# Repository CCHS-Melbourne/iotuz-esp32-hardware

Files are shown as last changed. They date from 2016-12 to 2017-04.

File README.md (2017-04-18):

IoTuz - The Internet of Tuz
=============

Welcome to the linux.conf.au 2017 Open Hardware Project.  You can see information about this and other MiniConfs at http://www.openhardwareconf.org/wiki/Main_Page

This year we're bringing a project with the hottest new micro for people to have a play with. The ESP32 is the successor to the hugely popular ESP8266 chip we used for 2016 Open Hardware Project, the (ESPlant, https://github.com/CCHS-Melbourne/ESPlant).

The ESP32 is definitely the big brother of the ESP8266.  Included in it's features: 2.4 GHz Wi-Fi, Bluetooth, Dual Core CPUs

As usual we've got a custom board and some custom software to get you started on your journey!  Check out the subdirectories in this repo for more information.

IoTuz firmware can be found at https://github.com/CCHS-Melbourne/iotuz-esp32-firmware

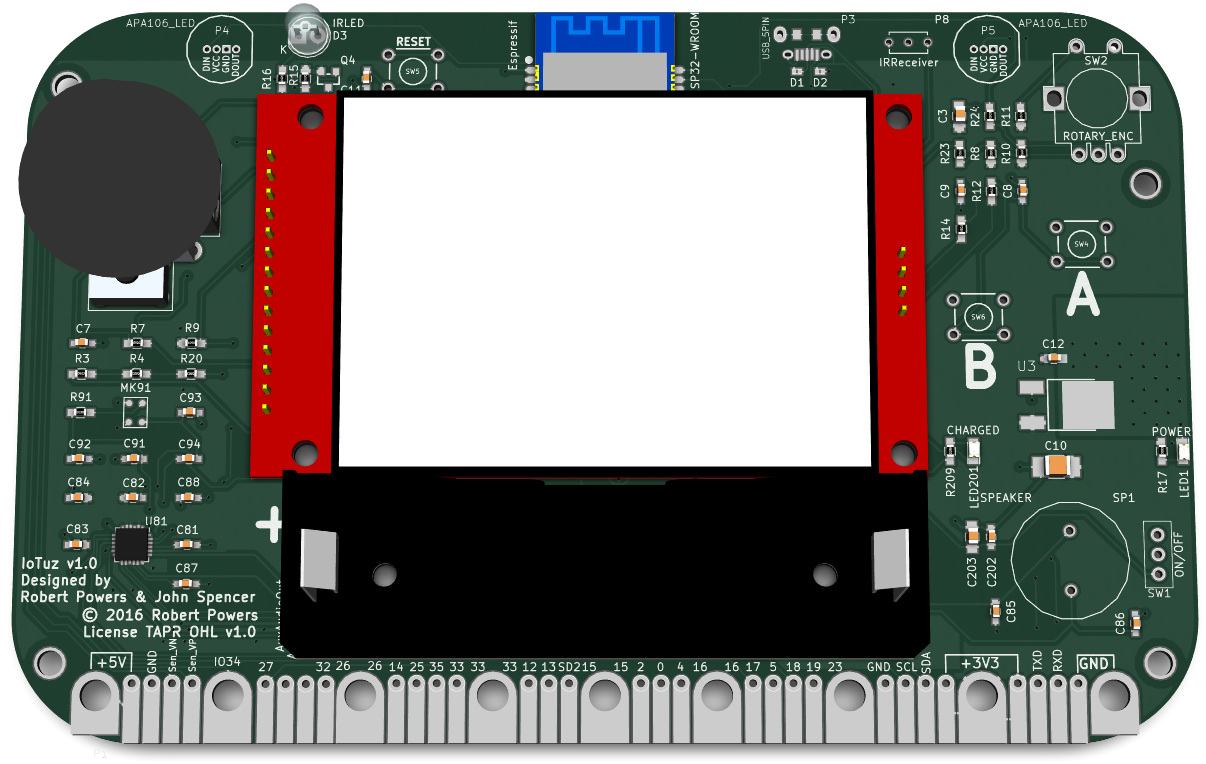
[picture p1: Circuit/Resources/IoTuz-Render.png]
IoTuz Render


Hardware assembly instructions
------------------------------
[Workshop assembly instructions](https://github.com/CCHS-Melbourne/IoTuz/wiki/Assembly-Instructions)
for people attending the LCA2017 Open Hardware Mini-Conference.

Software instructions
---------------------

[Software setup instructions](https://github.com/CCHS-Melbourne/IoTuz/wiki/Software-Instructions)

Please see https://github.com/marcmerlin/IoTuz mentioned below for an arduino driver.

Features
--------

[Marc MERLIN has written a driver for the arduino environment](https://github.com/marcmerlin/IoTuz) with support for:
- TFT (hw SPI)
- Touchscreen (hw SPI)
- Replacement touchscreen support (calibration option in case your touchscreen is reversed or has different calibration)
- Rotary Encoder via pin interrupt driven driver
- Support for A and B buttons "hidden" behind the I2C IO multiplexer
- Joystick
- Color LEDs
- Accelerometer
- BME280 (temperature, humidity, pressure)
- IO expander (pcf8574)
- Infrared receiver





For this software, go to: https://github.com/marcmerlin/IoTuz

Getting IoTuz
---------------
You need to clone the IoTuz repo from github, using the `--recursive` option to pick up submodules. If you download a zip file then the submodule parts will be missing, so we recommend using git to get it.

The command is:
```
git clone --recursive https://github.com/CCHS-Melbourne/IoTuz
```

Where to Now?
-------------

Check out (and contribute to) [the wiki](https://github.com/CCHS-Melbourne/IoTuz/wiki). There is a pinout summary, sensor summary, power information, etc.

CREDITS
------------

Made at hackmelbourne.org !

This project was designed by the 2017 linux.conf.au Open Hardware Team!
 - [Bob Powers](https://github.com/rdpowers)
 - [John Spencer](https://github.com/mage0r)
 - [Angus Gratton](https://github.com/projectgus)
 - [Andy Gelme](https://github.com/geekscape)
 - [Jon Oxer](https://github.com/jonoxer)
 - [Mark Wolfe](https://github.com/wolfeidau)
 - [Ian Firns](https://github.com/firnsy)

Art work: Tasmanian Devil ["Tuz" reference](http://www.redbubble.com/people/taniawalker/works/22375875-round-tasmania-vignettes) (C) 2016 by [Tania Walker](http://www.taniawalker.com).  License [CC-BY-NC-SA](https://creativecommons.org/licenses/by-nc-sa/2.0).  This art work is only going to be used on the PCB production run for the [LCA2017 Open Hardware Mini-Conference](http://www.openhardwareconf.org/wiki/OHC2017).

SPECIAL THANKS
------------

[EspressIF](https://espressif.com/) - The company behind the hugely popular ESP8266 chips we used in 2016 and the brand new ESP32 chips we're using this year.  EspressIF has kindly donated the ESP32 chips we'll be using on the boards.

To the [HackMelbourne](http://hackmelbourne.org) community of Melbourne, Australia.

The Desk Solder protectors feature graphics from [Adafruit Reference Cards](https://github.com/adafruit/Reference-Cards).

To all other open-source developers whose countless hours supported every other aspect of this design.

DISTRIBUTION
------------
The specific terms of distribution of this project are governed by the
license referenced below. Please contact the copyright owner if you wish to modify the board for distribution. Please utilize this design for personal or research projects. Please acknowledge all contributors.

LICENSE
-------
Licensed under the TAPR Open Hardware License (www.tapr.org/OHL).
The "LICENSE" file is a copy of this license in plain text format.

Copyright John Spencer, Bob Powers, Angus Gratton, Andy Gelme, Jon Oxer, Mark Wolfe 2016

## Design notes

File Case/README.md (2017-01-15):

IoTuz Case - A case for the Internet of Tuz board
=============

This case has been designed to be a "sandwhich" style case for your Internet of Tuz board.  It should fit snuggly over the battery socket and around the LCD touch screen.

This design was completed using Trimble Sketchup.  Not a particularly open source project, but one I actually know how to use.
A Board outline was exported as DXF from Kicad and that was used as exact measurements for holes and placements relative to the circuit board.

IoTuz Render

DISTRIBUTION
------------
The specific terms of distribution of this project are governed by the
license referenced below. Please contact the copyright owner if you wish to modify the board for distribution. Please utilize this design for personal or research projects. Please acknowledge all contributors.

LICENSE
-------
Licensed under the TAPR Open Hardware License (www.tapr.org/OHL).
The "LICENSE" file is a copy of this license in plain text format.

Copyright John Spencer, Bob Powers, Angus Gratton, Andy Gelme, Jon Oxer, Mark Wolfe 2016

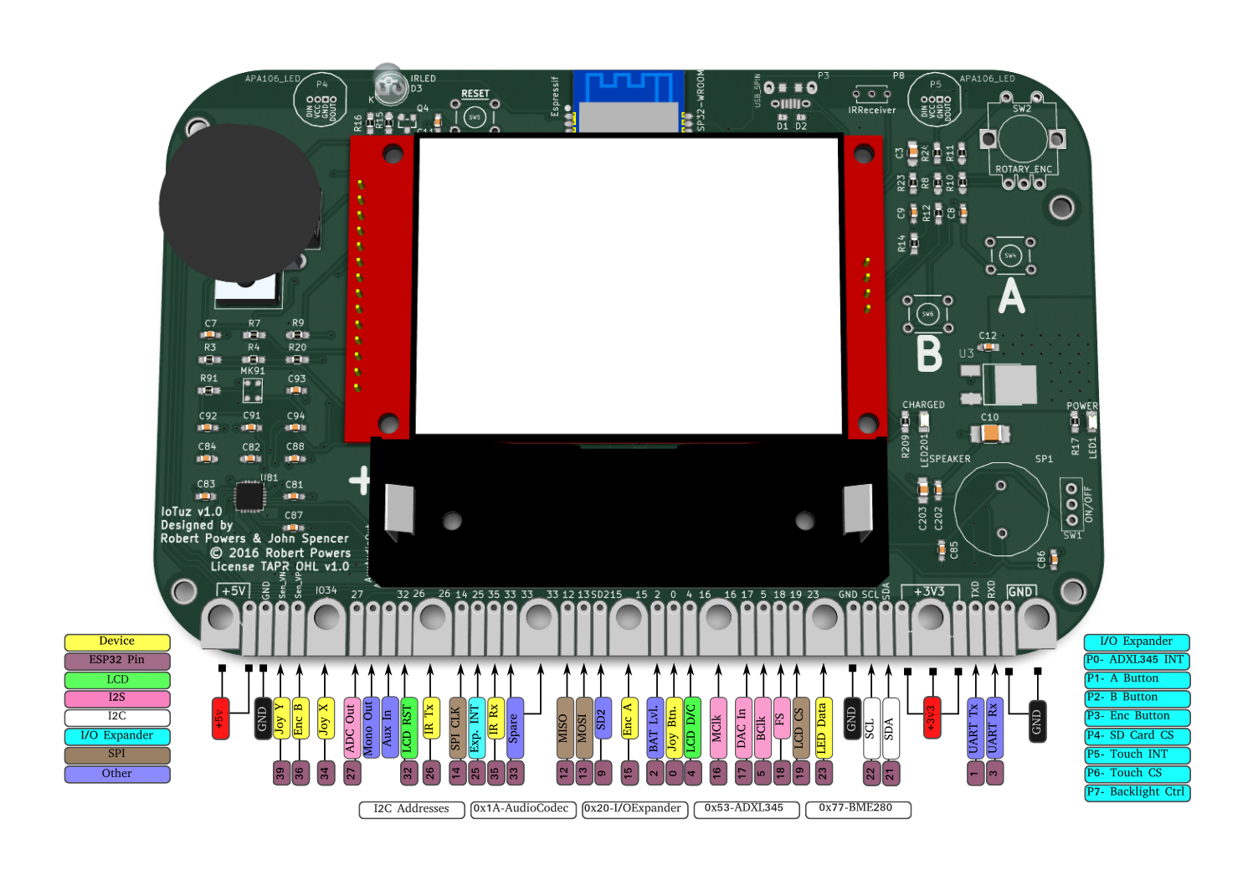
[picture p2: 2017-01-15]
Circuit/Resources/IoTuzPinout.png

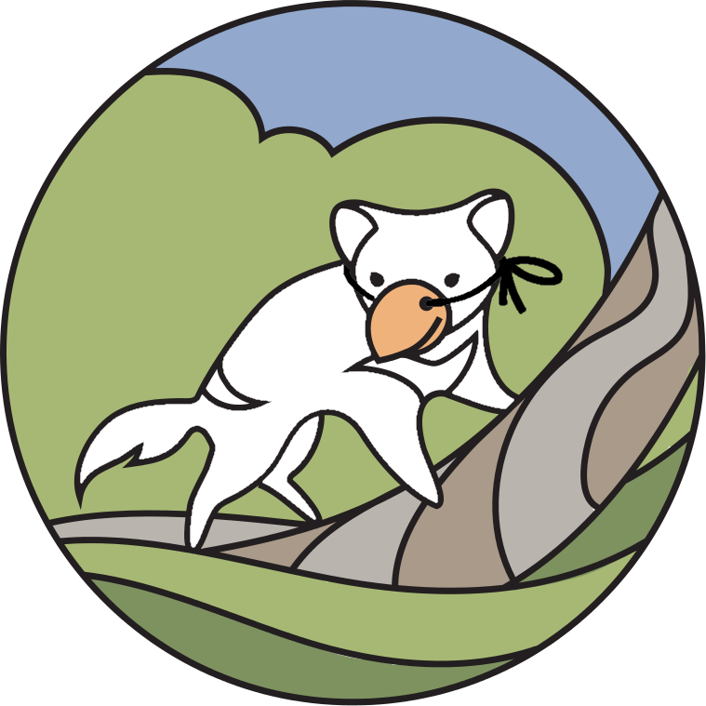
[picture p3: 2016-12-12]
Circuit/Reference/tuz.png

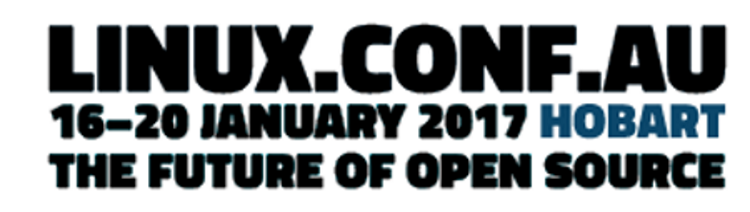
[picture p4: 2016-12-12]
Circuit/Reference/linuxconf.hobart.png

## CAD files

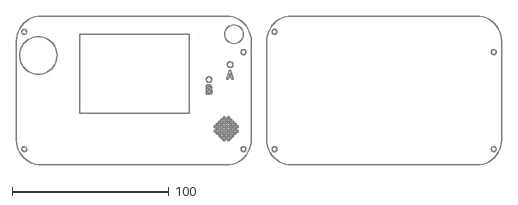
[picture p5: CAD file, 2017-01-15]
Case/IoTuz-case.dxf
310.0 x 95.1

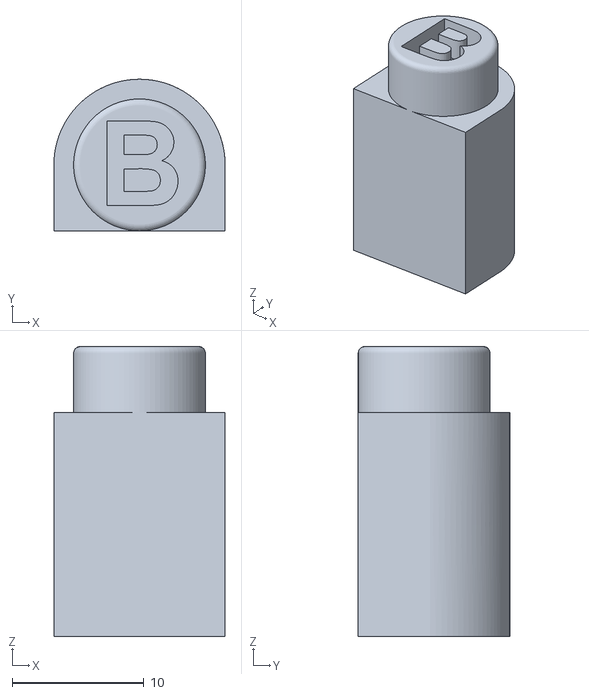
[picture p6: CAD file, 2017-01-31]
Case/Printable/Button Caps_ButtonB-20.5mm_Button Caps.stl
13.0 x 11.5 x 22.0

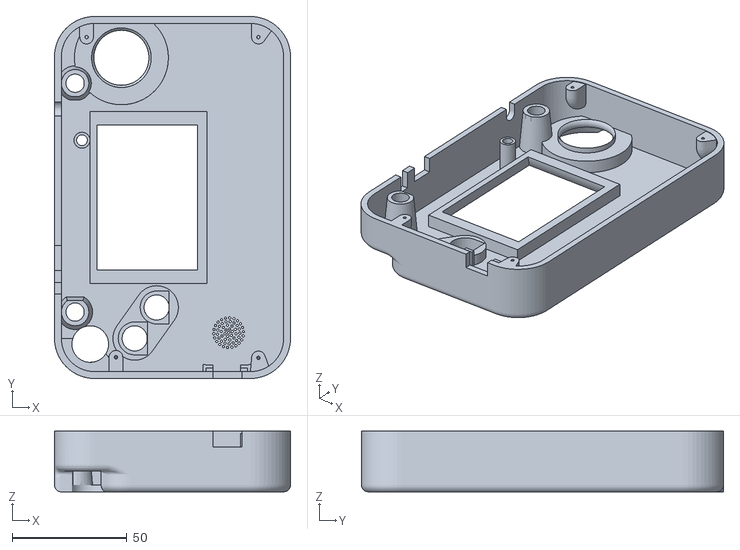
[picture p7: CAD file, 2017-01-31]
Case/Printable/Top_Case.stl
103.0 x 158.0 x 26.5

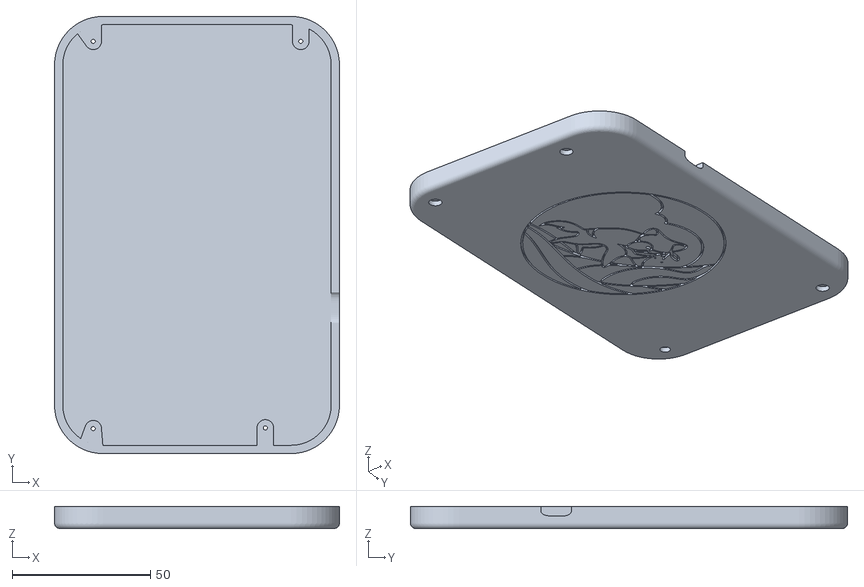
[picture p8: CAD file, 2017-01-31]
Case/Printable/Bottom_Case.stl
103.0 x 158.0 x 8.00

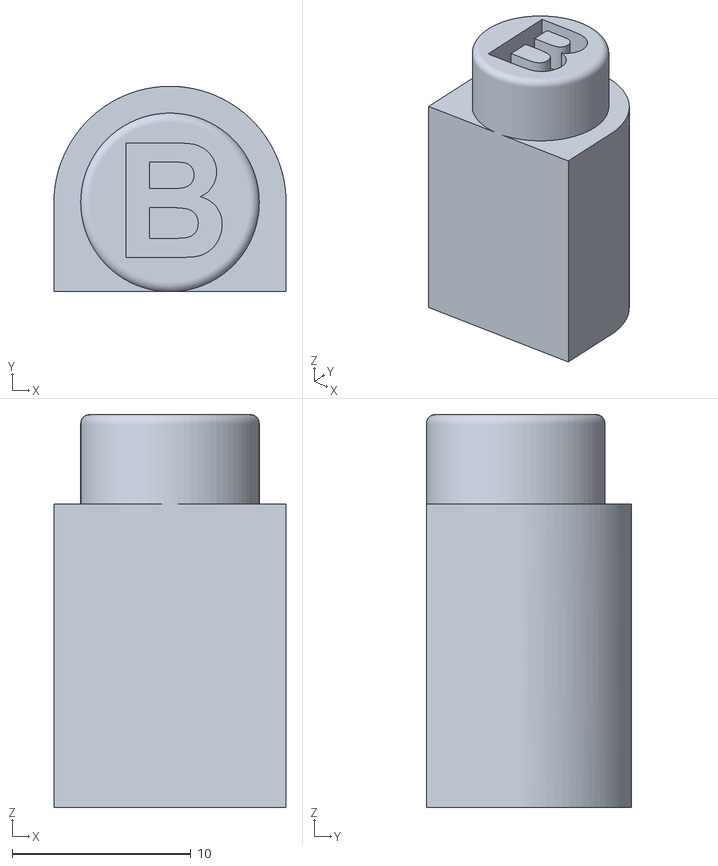
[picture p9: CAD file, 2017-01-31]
Case/Printable/Button Caps_ButtonB-6mm_Button Caps.stl
13.0 x 11.5 x 22.0

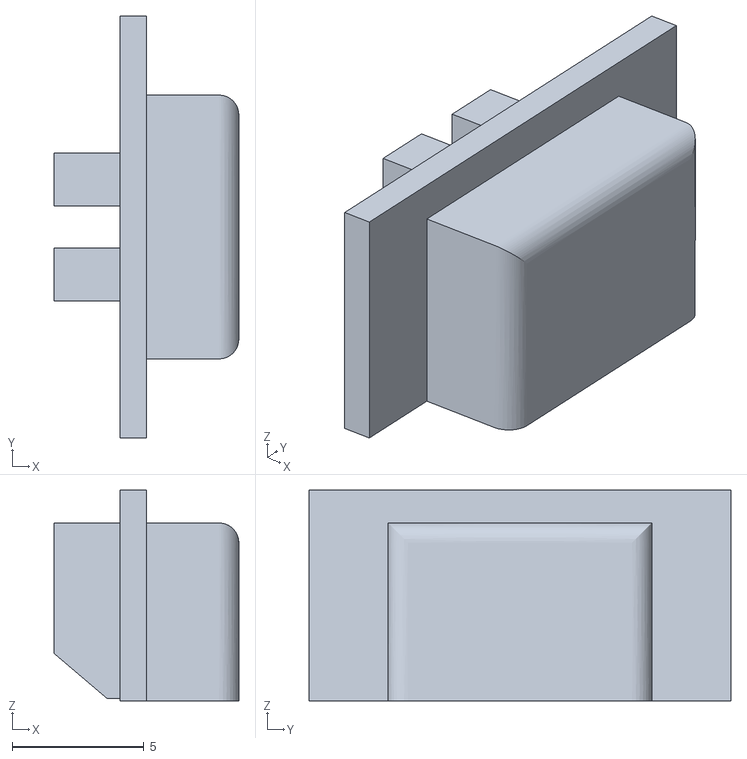
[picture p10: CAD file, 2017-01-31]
Case/Printable/Button Caps_Powerbutton_Button Caps.stl
7.00 x 16.0 x 8.00

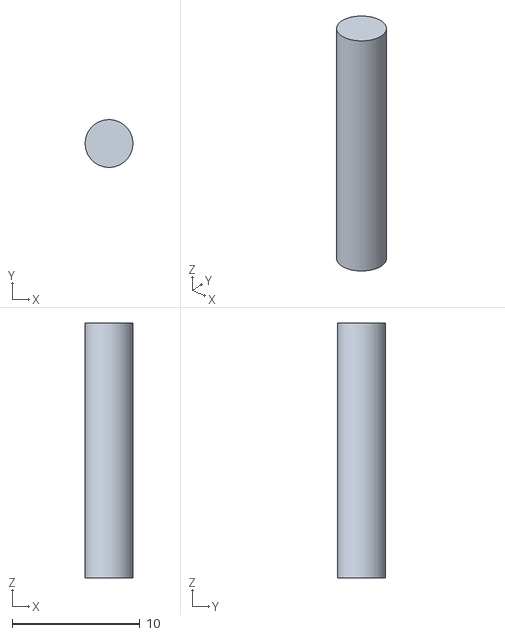
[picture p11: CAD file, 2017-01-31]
Case/Printable/Button Caps_ResetButton_Button Caps.stl
3.75 x 3.75 x 20.0

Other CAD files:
Case/Printable/Button Caps_ButtonA-20.5mm_Button Caps.stl
Case/Printable/Button Caps_ButtonA-6mm_Button Caps.stl
Case/IoTuz-case.skp

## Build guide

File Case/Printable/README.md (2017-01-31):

3D printable case, created in Fusion 360.

Print the top, bottom, reset button, power switch
 and one of the 2 sets of ButtonA and ButtonB button caps
depending on whether you have 6mm button stems like I do, or
the 20.5mm long stemmed buttons as originally supplied.

If you're like me, you might need to sand some of the openings
in the case top for smoothness so the buttons and joystick
don't stick.

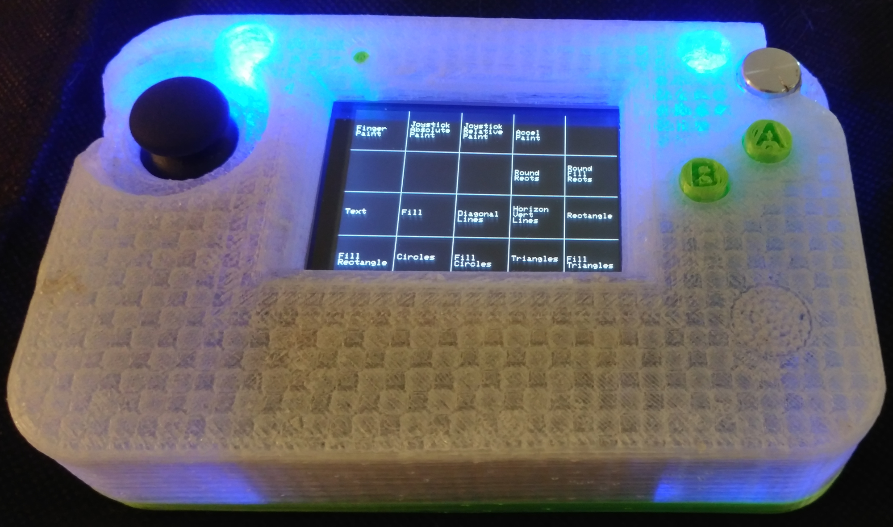
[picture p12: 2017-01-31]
Case/Printable/front-shot.jpg

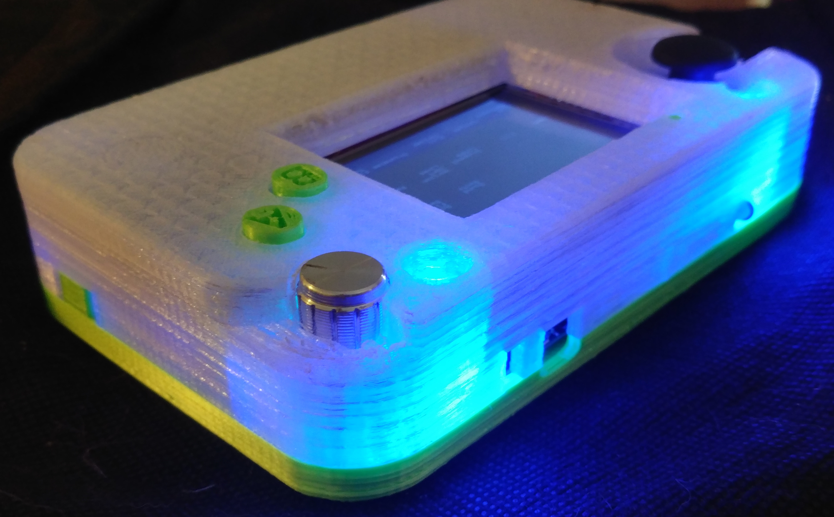
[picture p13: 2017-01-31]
Case/Printable/side-back.jpg

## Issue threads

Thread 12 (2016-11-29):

IO2 Strapping

rdpowers, 2016-11-29:
Pull-up on IO2 (R10) to rotary encoder prevents auto-reset to UART programming. Move off of IO2 to IO19.

rdpowers, 2016-12-05:
Move to VBAT monitor pin - at 1/10 of VBAT, this should always register a logic low. Worst case, have to remove the battery to program as the resistors will act as a pull-down in its absence.

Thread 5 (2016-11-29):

Bigger drills

mage0r, 2016-11-29:
For speaker (just fits).
For rotary encoder (doesn't fit signal pins)
APA106 (increase spacing)

mage0r, 2016-11-29:
Fixed spacing on APA106 footprint in 2107f38

mage0r, 2016-11-29:
Fixed hole sizes for encoder in 8cdbe23

rdpowers, 2016-11-30:
Add bigger pads around TH parts where possible to make hand-soldering easier. It's pretty small on the speaker, encoder, IRTx, & APA106. Wouldn't hurt to do it on all of the TH stuff though.

mage0r, 2016-12-01:
I've increased the pads on the speaker and the rotary encoder ones are already fairly big.  I can't do much about the apa106, it's pins are fairly close together and if I make the pads much larger we'll have problems with bridging.

rdpowers, 2016-12-03:
Did you increase the spacing of the APA106 pins? On second thought, this is probably not a good idea - they probably should have been closer if possible, or left alone if not.

mage0r, 2016-12-03:
I reduced them, but I haven't updated the PCB.  Same with the other footprints, They've been corrected in the kicad_mod files, but the change hasn't gone through the PCB yet.

mage0r, 2016-12-05:
Updated the pcb in e62c2e9

Closed 2016-12-05.

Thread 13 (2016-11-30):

IO15 Strapping

rdpowers, 2016-11-30:
Test & maybe swap IO15 from rotary encoder A to where IO26 is now - 1/10 battery level should effectively pull IO15 low to disable boot-debugging on UART TXD.

rdpowers, 2016-12-04:
In light of #18, battery level monitoring on IO26 should be moved to one of the input-only "GPIO" of SENSOR_VP or VDET2 (GPIO35) as they can be used as ADC input.

Closed 2016-12-06.

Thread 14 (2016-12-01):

Change pins on alligator connector

mage0r, 2016-12-01:
The existing alligator connector has some empty pins and some pin assignments that don't make sense.

Redesign it so that all pins are in use and so that there are more "large" pins available.

mage0r, 2016-12-05:
Updated the footprint and the pcb e62c2e9

Closed 2016-12-05.

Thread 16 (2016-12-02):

Turning Rotary Encoder Seems to Glitch ESP32

rdpowers, 2016-12-02:
Power LED blinks out, indicating temporary short to ground. Does not occur with button press.

rdpowers, 2016-12-03:
Datasheet seems to show 10k resistors on lines leading to uC I/O. Might be needed, but not sure if this will alleviate the problem.

rdpowers, 2016-12-04:
Proto #3 has bodged in 10k resistors inline with I/O. This seems to fix the earlier issues of browning out the 3v3 line. Should also add small cap. on those two lines, also as shown in datasheet, for debounce.

Closed 2016-12-06.

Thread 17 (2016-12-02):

Trace between Pins 2 and 12 of ADXL should not run under the chip.

rdpowers, 2016-12-02:
Under ADXL should be keepout.

mage0r, 2016-12-05:
Fixed in 513791c

Closed 2016-12-05.

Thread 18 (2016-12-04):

GPIO35 is not GPIO

rdpowers, 2016-12-04:
We can't use VDET2 (GPIO35) or VDET1 (GPIO34) as outputs. They can function as inputs in normal operation though (tested). GPIO35 is currently wired as output for LCD_CS.

From:
http://www.esp32.com/viewtopic.php?t=187

> Well, they belong to the RTC power domain, which means that the devices that fall under the RTC can control them. It means e.g. that they can be used as ADC pins and that the ULP coprocessor can read them. Apart from that, they can also be used as normal GPIOs and when the CPU is on, they can be routed as inputs to most peripherals over the GPIO mux. **They can't be outputs though, input only.**

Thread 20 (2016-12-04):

Keepout on mounting points

rdpowers, 2016-12-04:
Make sure to put keepouts on the MP THs, especially to keep off pours underneath screw heads.

mage0r, 2016-12-05:
Hrm, Kicad doesn't like drawing circles.  Maybe a larger copper pad?

mage0r, 2016-12-05:
And derp, fixed in 04e7c0e

Closed 2016-12-05.

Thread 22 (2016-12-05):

Move buttons B & A

rdpowers, 2016-12-05:
To my hands the B & A buttons are too close to the edge. They are about the right height. Suggest move left 5mm and down maybe slightly.

rdpowers, 2016-12-05:
Doing more measurements, I'd say left 5mm and increase vertical spacing by 3-5mm while keeping the vertical center of the buttons the same (move B down by 1.5-2.5mm/A up by 1.5-2.5mm). Horizontal spacing could increase too, but I'd rather have that A button more to the left than anything.

mage0r, 2016-12-05:
Fixed in e62c2e9 I hope.

Closed 2016-12-05.

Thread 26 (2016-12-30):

Solder mask on back of alligator clips

mage0r, 2016-12-30:
Is missing.

mage0r, 2016-12-30:
Fixed dd45f39

Closed 2016-12-30.

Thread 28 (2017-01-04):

Reset Button

rdpowers, 2017-01-04:
Reset button might be unreliable.

Might be made more reliable by shorting R13 (470R) on input to switch. Testing needed.

rdpowers, 2017-01-30:
On 2x test boards shorting R13 (470R) makes the reset button work much more as expected. Suggest smaller or 0R resistor with debounce cap, or removal entirely.

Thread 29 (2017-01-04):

Reset after programming

rdpowers, 2017-01-04:
Can anything be done in software to initiate reboot and code run after programming finishes? At current, reset is required after programming.

projectgus, 2017-01-04:
This is available in latest esp-idf as of about a day ago, should be avaible in Arduino soon also.

rdpowers, 2017-01-10:
Looks like this is working. Thanks @projectgus for letting me know it was on it's way!

Closed 2017-01-10.

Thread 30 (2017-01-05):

X & Y Pinout on Joystick Reversed

rdpowers, 2017-01-05:
Minor oversight in pinout of joystick. X pins are Y pins and Y pins are X pins.

mage0r, 2017-01-05:
Are you sure this is still an issue?

At one point I switched the x and y over because the joystick was being mounted 90 degrees off on the board.

rdpowers, 2017-01-05:
Yes. In reality, the X pot is aligned along the Y axis and vice-versa. Takes a second to realise that actuation means it needs to rotate about the tangent axis so intuition about what's X and what's Y is not normal.

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

Also needs updating in documentation, so probably leave this open until that's fixed up as well.

mage0r, 2017-01-05:
Hrm, I definitely re-labelled something to try and fix that.

It might have been the labels on the schematic.  but then, they're just text labels so they could have been fixed back up.

Is the pin list on the back wrong?

rdpowers, 2017-01-05:
Yes, that is incorrect also in the same way.

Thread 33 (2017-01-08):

i2c Pull-up Values

rdpowers, 2017-01-08:
Current value of 4k7 might not be optimal. Timing issues being investigated.

rdpowers, 2017-01-21:
Does anyone still suspect any issues around timing on the i2c bus?

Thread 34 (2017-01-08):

i2s Impedance Matching?

rdpowers, 2017-01-08:
Some other implementations have in-line resistors for impedance matching. Not sure if this is an issue or not, but worth placing some 0-ohms in next revision for testing if i2s has problems.

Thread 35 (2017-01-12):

Missing Assembly BOM Items

rdpowers, 2017-01-12:
U201, R23, R24 weren't on the assembly BOM for v1.0.

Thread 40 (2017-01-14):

Fuse from assembly house was not good. Very not good.

rdpowers, 2017-01-14:
Make sure this is the case and specify no component replacement for this item in future.

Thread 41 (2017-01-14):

MCP6002 Pinout Wrrrrrong.

rdpowers, 2017-01-14:
Someone changed the schematic pinout in the library. Pins 5 & 6 got swapped and now perform the wrong function as v1.0 schematic has them wired. This is why you never use someone else's parts library.

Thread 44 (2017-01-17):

Adafruit_ILI9341.cpp doesn't work without patch

marcmerlin, 2017-01-17:
I've compiled graphicstest.ino and it fails to build
/home/merlin/Arduino/libraries/Adafruit_ILI9341/Adafruit_ILI9341.cpp: In member function 'void Adafruit_ILI9341::spiwrite(uint8_t)':
/home/merlin/Arduino/libraries/Adafruit_ILI9341/Adafruit_ILI9341.cpp:113:3: error: 'mosiport' was not declared in this scope
  *mosiport |=  mosipinmask;
   ^

In Adafruit_ILI9341.cpp:96, I added a single define to select the correct code, and then everything works:
#define ESP8266
#if defined(ESP8266) || defined (ARDUINO_ARCH_ARC32)

I used the arduino installer for the lib and installed lib 1.0.1 and it didn't work until I patched it.
Not sure if the board file for ESP32 is supposed to define  ESP8266 or if the adafruit lib is supposed to detect a #define ESP32

marcmerlin, 2017-01-17:
I also updated my arduino IDE from 1.6.7 to 1.8.1 and it didn't help, same problem, but the workaround still works.

projectgus, 2017-01-17:
The ESP32 board file can't safely pretend to be an ESP8266, because it isn't one! Lots of system-level APIs are different so some Arduino libraries would error out / crash.

I think eventually the popular Arduino libraries will be all updated to support ESP32. The hard thing about some of these libraries is they're not hardware agnostic, so someone has to add the relevant support

I expect if you send Adafruit a pull request that said "I needed this `|| defined(ESP32)` for ESP32 Arduino support and it worked afterwards", then they'd accept it.

marcmerlin, 2017-01-17:
That sounds more than reasonable, except it works for others without this patch, but I'm worried I have something wrong on my side. Once we figure out that the adafruit library is indeed in need of that patch, I'll send it, I just would like to know why it works for others without the patch :)

mage0r, 2017-01-17:
I can confirm the same problem.  I fixed mine using the method suggested by Angus.

marcmerlin, 2017-01-17:
Looks like it's already upstream, just not in the released version?
https://github.com/adafruit/Adafruit_ILI9341/blob/master/Adafruit_ILI9341.cpp#L98

marcmerlin, 2017-01-17:
Added warning in the code
https://github.com/CCHS-Melbourne/iotuz-esp32-hardware/pull/45

Closed 2017-01-17.

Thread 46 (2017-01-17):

Are APA106 LEDs missing recommended cap? Has anyone gotten them to work?

marcmerlin, 2017-01-17:
Looking at the top right of the first page of https://github.com/CCHS-Melbourne/iotuz-esp32-hardware/raw/master/Circuit/Resources/IoTuz-Schematic.pdf (took me a while to locate them :) ), they do not seem to have any cap.

https://learn.adafruit.com/adafruit-neopixel-uberguide/individual-neopixels says
"It’s very strongly recommended that each NeoPixel have an accompanying 0.1 μF capacitor between +V and ground. This prevents communication problems due to brownout of the on-pixel driver logic. It’s occasionally sufficient to have one capacitor between pairs of pixels; some of our NeoPixel rings work that way."

Is that an issue for the design in this board?
More generally has anyone managed to talk to them with the neopixel library?
So far I have
#include "Adafruit_NeoPixel.h"
#define RGB_LED_PIN 23
#define NUMPIXELS 2
Adafruit_NeoPixel pixels = Adafruit_NeoPixel(NUMPIXELS, RGB_LED_PIN, NEO_GRB + NEO_KHZ800);
pixels.begin();
pixels.setPixelColor(0, pixels.Color(255, 0, 0));
pixels.setPixelColor(1, pixels.Color(0, 255, 0));
pixels.show();

And nothing happens.
I've also noticed that sometimes (rarely) when you boot/power the board, the LEDs come with a different color, meaning that noise comes to them and get taken as a command.

wolfeidau, 2017-01-17:
I have been looking into the software side of this https://github.com/FastLED/FastLED supports the apa106 but doesn't have ESP32 support. We are discussing forking it and working with @projectgus to get it working.

Will keep you updated!

rdpowers, 2017-01-21:
As probably seen, this has been solved in software.

@marcmerlin is right that adhering to the datasheet is a good idea even when you know you can get away with it otherwise. Tagging as enhancement for next revision.

marcmerlin, 2017-06-06:
just found this old bug. The neopixel library wasn't working because it didn't have any code at all for ESP32. I added some, so now it does :)
Whether the cap is actually necessary for a couple of pixels, now that I'm thinking about it again, the answer is likely no, so feel free to close if you wish.

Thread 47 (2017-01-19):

I2C expander pin mapping on back of the board is wrong

marcmerlin, 2017-01-19:
It says
Touch_CS P5
Touch_IRQ P6

If I follow https://github.com/CCHS-Melbourne/iotuz-esp32-hardware/raw/master/Circuit/Resources/IoTuz-Schematic.pdf those two pins are assigned the other way around

rdpowers, 2017-01-23:
Good catch @marcmerlin. Thanks.

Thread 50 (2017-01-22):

Missing Mic

PeteLawler, 2017-01-22:
The iotuz board as delivered at LCA is missing the mic and I asked for some documentation on how to hack it on and was told to submit an issue and this is that issue.

rdpowers, 2017-01-23:
[Bodge instructions](https://github.com/CCHS-Melbourne/iotuz-esp32-hardware/wiki/Assembly-Instructions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) are posted here.

Please let me know if they are incomplete or difficult to follow.

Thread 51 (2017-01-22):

Board doesn't turn on with power-only USB

voltagex, 2017-01-22:
Not sure if that's the correct title - I mean that the board won't turn on (screen remains off) if I plug the board into a USB charger with no battery inserted.

Plugging it into a PC or laptop works fine

rdpowers, 2017-01-23:
There's nothing special about the data lines, so I suspect your USB charger or the on-board USB connector.

Do you have a DMM/voltmeter?

What I would first do is check the 5V line when you have plugged it in by the charger. Is it near 5V? If you wriggle the connector does the power LED come on, even briefly (the switch will need to be in the ON position)? Does another charger work?

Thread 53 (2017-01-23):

io expander is listed as having 2 IO ports on the back of the board

marcmerlin, 2017-01-23:
@rdpowers, the back of the board mentions: 0x20 and 0x40
The spec sheet seems to imply (from what I read) that if 0x20 is the write port, 0x21 is the read port, and yet the version we have seem to work with a single I/O port, or at least does not have 2 IO ports that I was able to find from any scan or anything else.

Assuming that indeed that expander only has a single IO port, the other one should be removed from the back of the board

rdpowers, 2017-01-24:
I think there's some confusion due to the strangeness encountered in 7-bit versus 8-bit addressing on i2c busses. There is only one device address - 0x20. This is the 7-bit address 0x20 = 010 | 0000 (note the '|' is showing where the separator is and that the upper nibble only has 3 bits). This is how you will access using the Wire library in Arduino.

Basically that library hides the convention that the last of 8 bits is used for a read/write flag. When you do Wire.read(), the library is taking the 7-bit address and appending a '0' as least-significant-bit. So you end up with a read address of, wait for this, 0x40 = 0100 | 0000. What happens, quite stupidly, is that the convention for referring to i2c address says you move the nibble-separator to where you would expect it to be for 8 bits (now the top nibble has 4 bits!! insane!) and introduce a pile of confusion. Similarly for the Wire.write() address of 0x41 = 0100 | 0001.

Datasheet for the PCF8574 on page 5 (7.1.1 Address maps) might make a little more sense than what I just wrote.. we've tied the address lines to all low, so the first line of Table 4 corresponds to our situation.

I don't think there's a reference to 0x40 on the v1.0 board (am I missing it? I am very bad at finding things). Maybe you're seeing "IO Exp irpt: IO4"? It is difficult to read and could be confused for 40, especially as that is coincident with the 8-bit "write" i2c address (0100 | 0000) for the IO expander.

Clear as mud?

marcmerlin, 2017-01-25:
@rdpowers  thanks for the detailled answer, I had no idea that the wire library would magically change the IO address and that this is why things worked.
I did see 0x40 written somewhere, but I can't find it anymore, so it must have been online and must have been fixed already.
Either way, now I understand how that IO expander is actually supposed to work, and I'll write more comments in my example code so that it's clear for others too.
Thanks much

Closed 2017-01-25.

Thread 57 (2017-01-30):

Bulk Caps

rdpowers, 2017-01-30:
Move 100uF decoupling SMD close to ESP32, place 220-440uF additional C on 3v3 line.

Should solve occasional brown-out issues.

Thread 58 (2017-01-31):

Overhang on USB

rdpowers, 2017-01-31:
USB connector can be moved slightly closer to edge to overhang properly. As is, it sits on the lip a little and  could cause production issues.

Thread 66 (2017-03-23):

move LCD backlight control to direct I/O pin

marcmerlin, 2017-03-23:
like pin 2.
Why?
1) getting basic TFT example code is a pain in the rear due to the amount of extra code required just to turn the LCD backlight on
2) to dim the LCD, you need to do PWM, and doing it via the port expander is too slow and too expensive to work well

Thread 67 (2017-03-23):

Pins 37/38 are unused, high res input only, use one of them for battery and free up GPIO2

marcmerlin, 2017-03-23:
GPIO 2 could be better used for other things like https://github.com/CCHS-Melbourne/iotuz-esp32-hardware/issues/66
Actually the GPIO used for the IR receiver could also be moved to pin37, freeing up a 2nd GPIO for the user.

rdpowers, 2017-04-20:
GPIO 37/38 (SENSOR_CAPP/SENSOR_CAPN) are not available on the WROOM module, so this is not feasible.

marcmerlin, 2017-04-20:
Ah, I had no idea. Thanks for that info. So basically there are 0 free ports on that chip. Someone not using the I2S support can probably re-use some of the ports, but that's it.
As extra credit, it would interesting to have a list of ports by port number, and show which ones could be re-used with either input or output if you ignore/not use their original purpose.
For instance, let's say port 2 would be re-used as output (maybe?) if you forgo its original use of a battery monitor (since that function isn't working anyway due to how unreliable analogread seems to be at this time).

Closed 2017-04-20.

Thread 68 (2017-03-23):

flashing over gives CRC errors that will not go away unless entire board is power cycled, or LCD power is removed

marcmerlin, 2017-03-23:
This depends on what you flash, and maybe whether the LCD is on and what's it's displaying at the time you're flashing (not positive on that).
Seems like an inductance problem.

example error:
Wrote 433536 bytes (199673 compressed) at 0x00010000 in 3.1 seconds (effective 1128.5 kbit/s)...
File  md5: 0792ec26eccb61687ea28d9813277886
Flash md5: 5c6aa8fb63042f23e65f3dd6b174fa72
MD5 of 0xFF is c6525a1270c88fcc86112d95347adaf8

rdpowers, 2017-04-20:
I haven't been able to replicate this on 3 different boards. Needs more investigation. Is there a specific binary that is more/less problematic? I'm intrigued.

marcmerlin, 2017-04-20:
I think it was dependent on what I was running at the time on the board before flashing to it.
I ended up "fixing" this by bending the LCD power pin and connecting it to a wire and a switch.
Strangely, just doing so, seemed to have change the inductance of the circuit in a way that the flashing problem went away and I never had to flip the switch to off.
This was not a one off with my board because the previous board I had, had the same issue, and the board that was loaned to me during LCA, also had he same issue.
I however have a replacement LCD I had to buy off ebay, it's pin compatible but not the same than the broken one, and that one does not seem to have the problem (or the problem went away on its own, or for a different reason).
I think you got my IoTuz code to run, you could run that, selecte demosauce to load up the CPU and LCD, and then try to fly something else from arduino.
If that works, then I'm not sure what to say.

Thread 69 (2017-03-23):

BME280 placement causes temp readings 10C too high due to chip placement?

marcmerlin, 2017-03-23:
When I booted my board, it showed 19C which was just about right.
15mn later once the board has run for a while, things warm up, and now it's showing 28C
Yesterday, I put the board (running) in the freezer and got a temp of 5C.
It seems that the board runs warm enough to affect the temp sensor.

marcmerlin, 2017-03-23:
Ok, I did the freezer experiment again but this time I turned the board off. Then I took it out and turned it on right away.  I got a temperature of -0.89C  It feels too warm for a freezer, but confirm again that the board running is definitely raising the board temperature in a measureable way.

rdpowers, 2017-04-20:
Ok, interesting. The normal usage would have cutouts and plane/fill removal around the BME280 to prevent this. I suspected that, given the area, the thermal mass of the PCB would be sufficient to counteract such heating. 5-10C is pretty significant, so this should be mitigated if possible in the next revision.

marcmerlin, 2017-04-20:
run my iotuz code on your board and give it a shot, see what you get.

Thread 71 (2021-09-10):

ESPHome configuration

jasonblewis, 2021-09-10:
I've been working on driving the IoTuz board using [ESPHome](https://esphome.io/).

here is my esphome config in case anyone else wants to have a go.

most peripherals are supported in esphome I believe.

```
esphome:
  name: iotuz
  platform: ESP32
  #board: nodemcu-32s
  board: esp32dev
  platformio_options:
#    upload_speed: 115200
#    upload_speed: 256000
#    upload_speed: 512000
    upload_speed: 921600

wifi:
  networks:
    - ssid: !secret homen_ssid
      password: !secret homen_psk
      priority: 80
    - ssid: !secret home_ssid
      password: !secret home_psk
      priority: 90
    - ssid: !secret work_ssid
      password: !secret work_psk
      priority: 100

#   # Enable fallback hotspot (captive portal) in case wifi connection fails
#   ap:
#     ssid: "Iotuz Fallback Hotspot"
#     password: !secret fallback_pw

# Enable Home Assistant API
api:
  password: !secret ha_api_pw

ota:
  password: !secret ota_pw

# captive_portal:

# Enable logging
logger:
  level: DEBUG

light:
  - platform: neopixelbus
    type: RGB
    pin: GPIO23
    num_leds: 2
    name: "NeoPixel Light"

i2c:
  sda: 21
  scl: 22
  scan: True
  id: bus_a

sensor:
  - platform: bme280
    temperature:
      name: "BME280 Temperature"
      oversampling: 16x
    pressure:
      name: "BME280 Pressure"
    humidity:
      name: "BME280 Humidity"
    address: 0x77
    update_interval: 60s
  - platform: rotary_encoder
    name: "Rotary Encoder"
    pin_a: 15
    pin_b: 36
  # - platform: adc
  #   pin: 39
  #   name: "analogue joystick X"
  #   update_interval: 500ms
  #   attenuation: 11db
  # - platform: adc
  #   pin: 34
  #   name: "analogue joystick Y"
  #   update_interval: 500ms
  #   attenuation: 11db
# #  - platform: adc
# #    pin: 2
# #    name: "Battery Level"
# #    update_interval: 60s
# #    attenuation: 11db

# Example configuration entry
pcf8574:
  - id: 'pcf8574_hub'
    address: 0x20
    pcf8575: False

# Individual outputs
binary_sensor:
  - platform: gpio
    name: "Joystic Button"
    pin:
      number: 0
      mode: INPUT
      inverted: True
  - platform: gpio
    name: "Button A"
    pin:
      pcf8574: pcf8574_hub
      # Use pin number 0
      number: 1
      # One of INPUT, INPUT_PULLUP or OUTPUT
      mode: INPUT
      inverted: True
    on_release:
      then:
        - switch.toggle: lcd_backlight

  - platform: gpio
    name: "Button B"
    pin:
      pcf8574: pcf8574_hub
      # Use pin number 0
      number: 2
      # One of INPUT, INPUT_PULLUP or OUTPUT
      mode: INPUT
      inverted: True

  - platform: gpio
    name: "Encoder Button"
    pin:
      pcf8574: pcf8574_hub
      number: 3
      # One of INPUT, INPUT_PULLUP or OUTPUT
      mode: INPUT
      inverted: True

# remote_transmitter:
#   pin: 26
#   carrier_duty_percent: 50%

# # Individual switches
switch:
#   - platform: template
#     name: Panasonic TV Off
#     turn_on_action:
#       remote_transmitter.transmit_panasonic:
#         address: 16388
#         command: 16825533
  - platform: gpio
    name: "LCD Backlight"
    id: lcd_backlight
    pin:
      pcf8574: pcf8574_hub
      # Use pin number 0
      number: 7
      # One of INPUT, INPUT_PULLUP or OUTPUT
      mode: OUTPUT
      inverted: True
    restore_mode: ALWAYS_ON

# remote_receiver:
#   pin: 35
#   dump: all

# # Example configuration entry
spi:
  clk_pin: GPIO14
  mosi_pin: GPIO13
  miso_pin: GPIO12

font:
  - file: "fonts/slkscr.ttf"
    id: my_font
    size: 20

color:
  - id: my_red
    red: 100%
    green: 20%
    blue: 25%
    white: 0%

# # Example minimal configuration entry
display:
  - platform: ili9341
    model: TFT 2.4
    cs_pin: 19
    dc_pin: 4
    led_pin: 32  ### see note below ###
    reset_pin: 32
    rotation: 270
    lambda: |-
      it.fill(Color::BLACK);
      it.print(0, 0, id(my_font), id(my_red), TextAlign::TOP_LEFT, "Hello World!");
```

Closed 2021-09-10.

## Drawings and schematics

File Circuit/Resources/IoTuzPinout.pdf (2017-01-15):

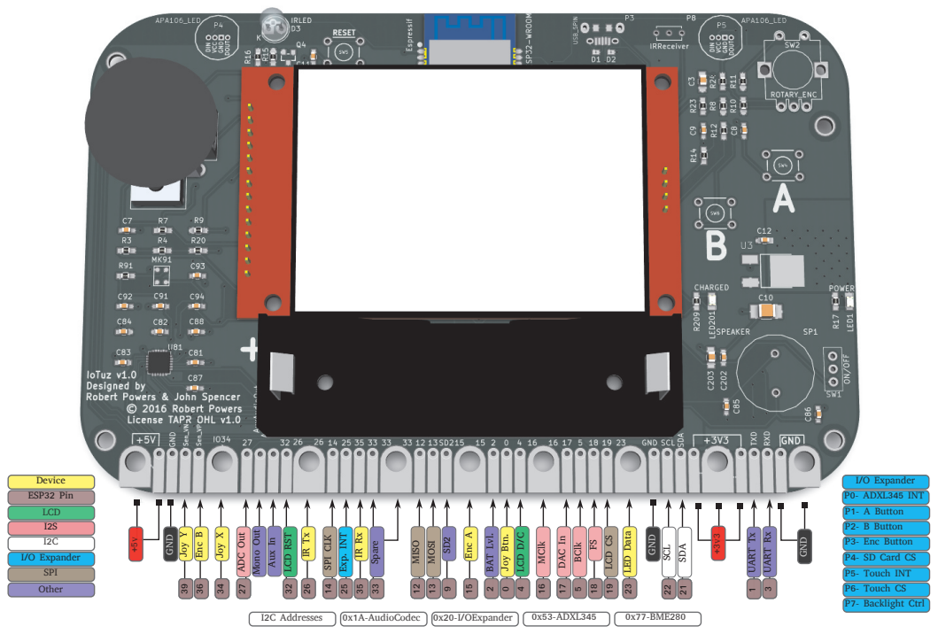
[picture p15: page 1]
Mono Out; GND; Joy Y 39; Enc B 36; Joy X 34; ADC Out 27; LCD RST 3; Aux In; Spare 33; Exp. INT 25; SPI CLK 14; 13 MOSI; Enc A 15; 12 MISO; 0 Joy Btn.; 2 BAT Lvl.; LCD D/C 4; MClk 16; DAC In 17; LCD CS 19; BClk 5; 23 LED Data; 22 SCL; SDA 21; UART Tx 1; UART Rx 3

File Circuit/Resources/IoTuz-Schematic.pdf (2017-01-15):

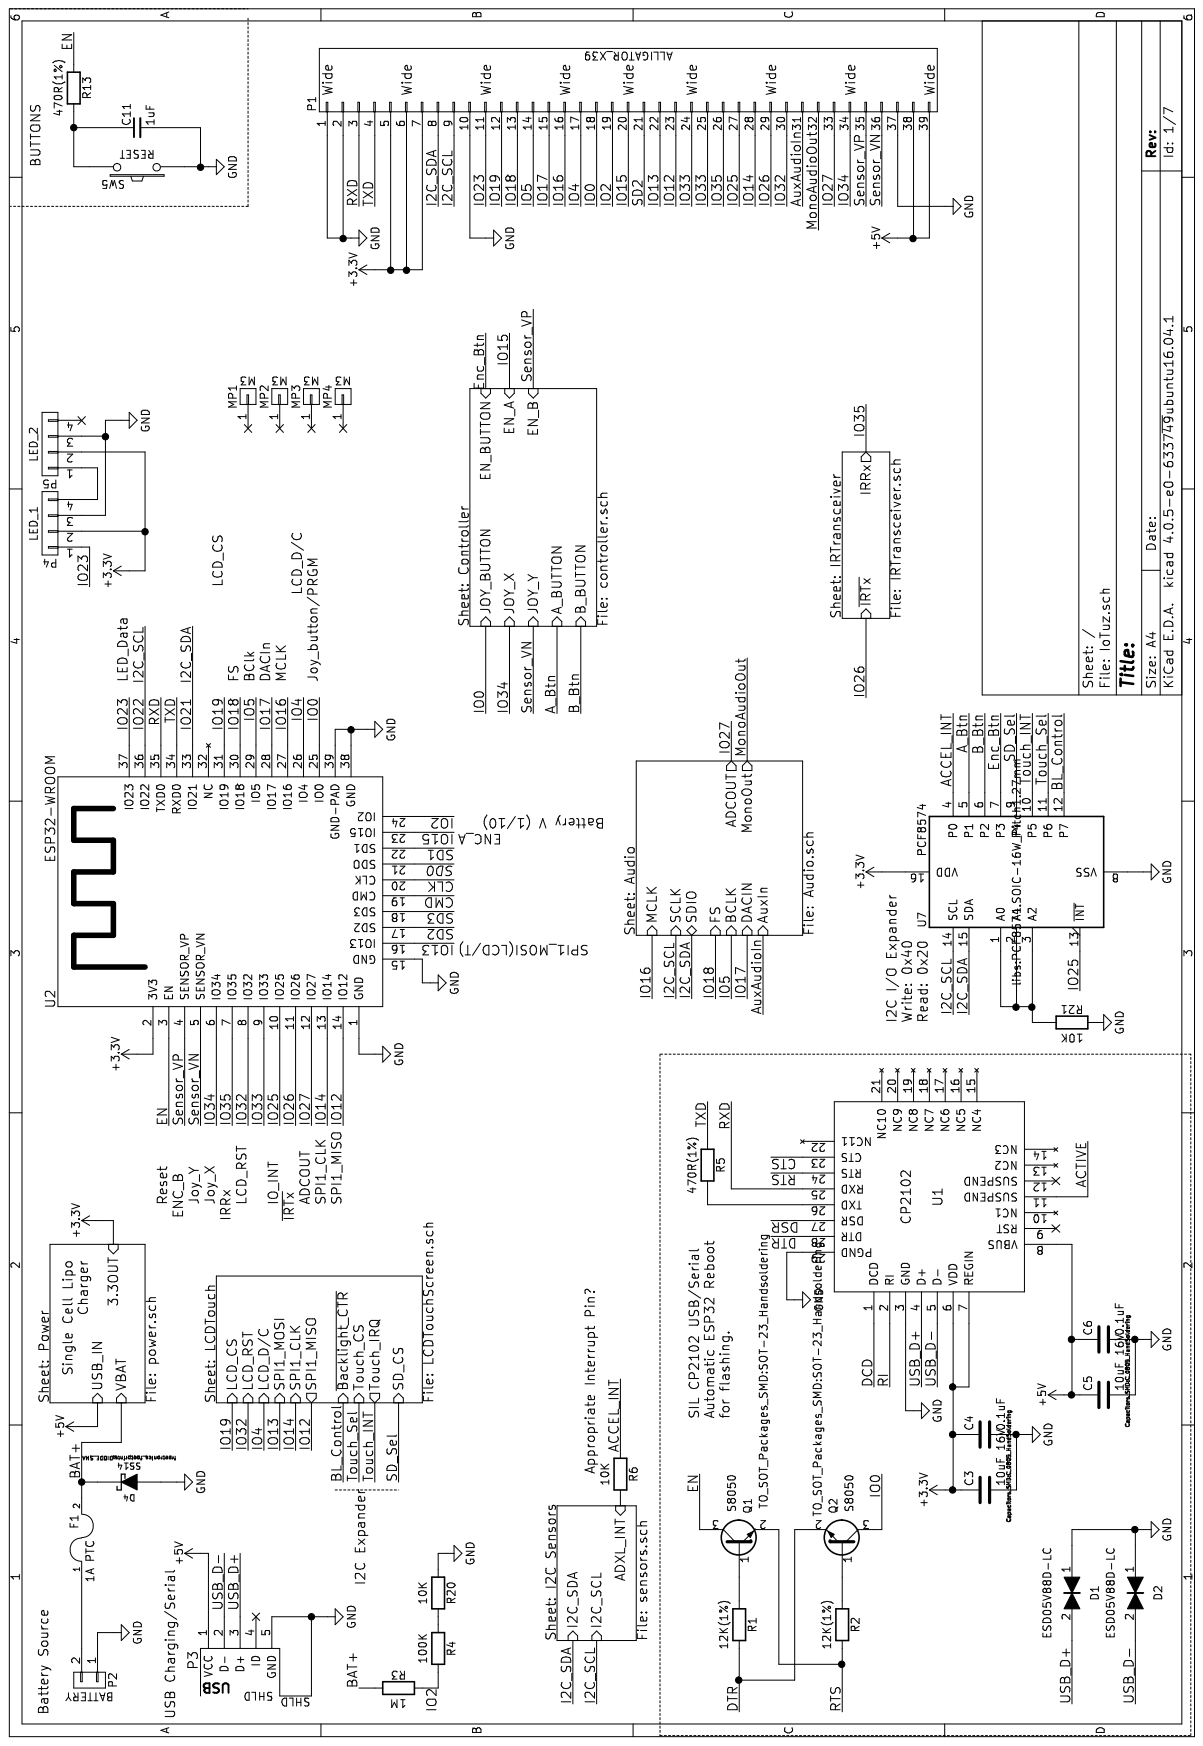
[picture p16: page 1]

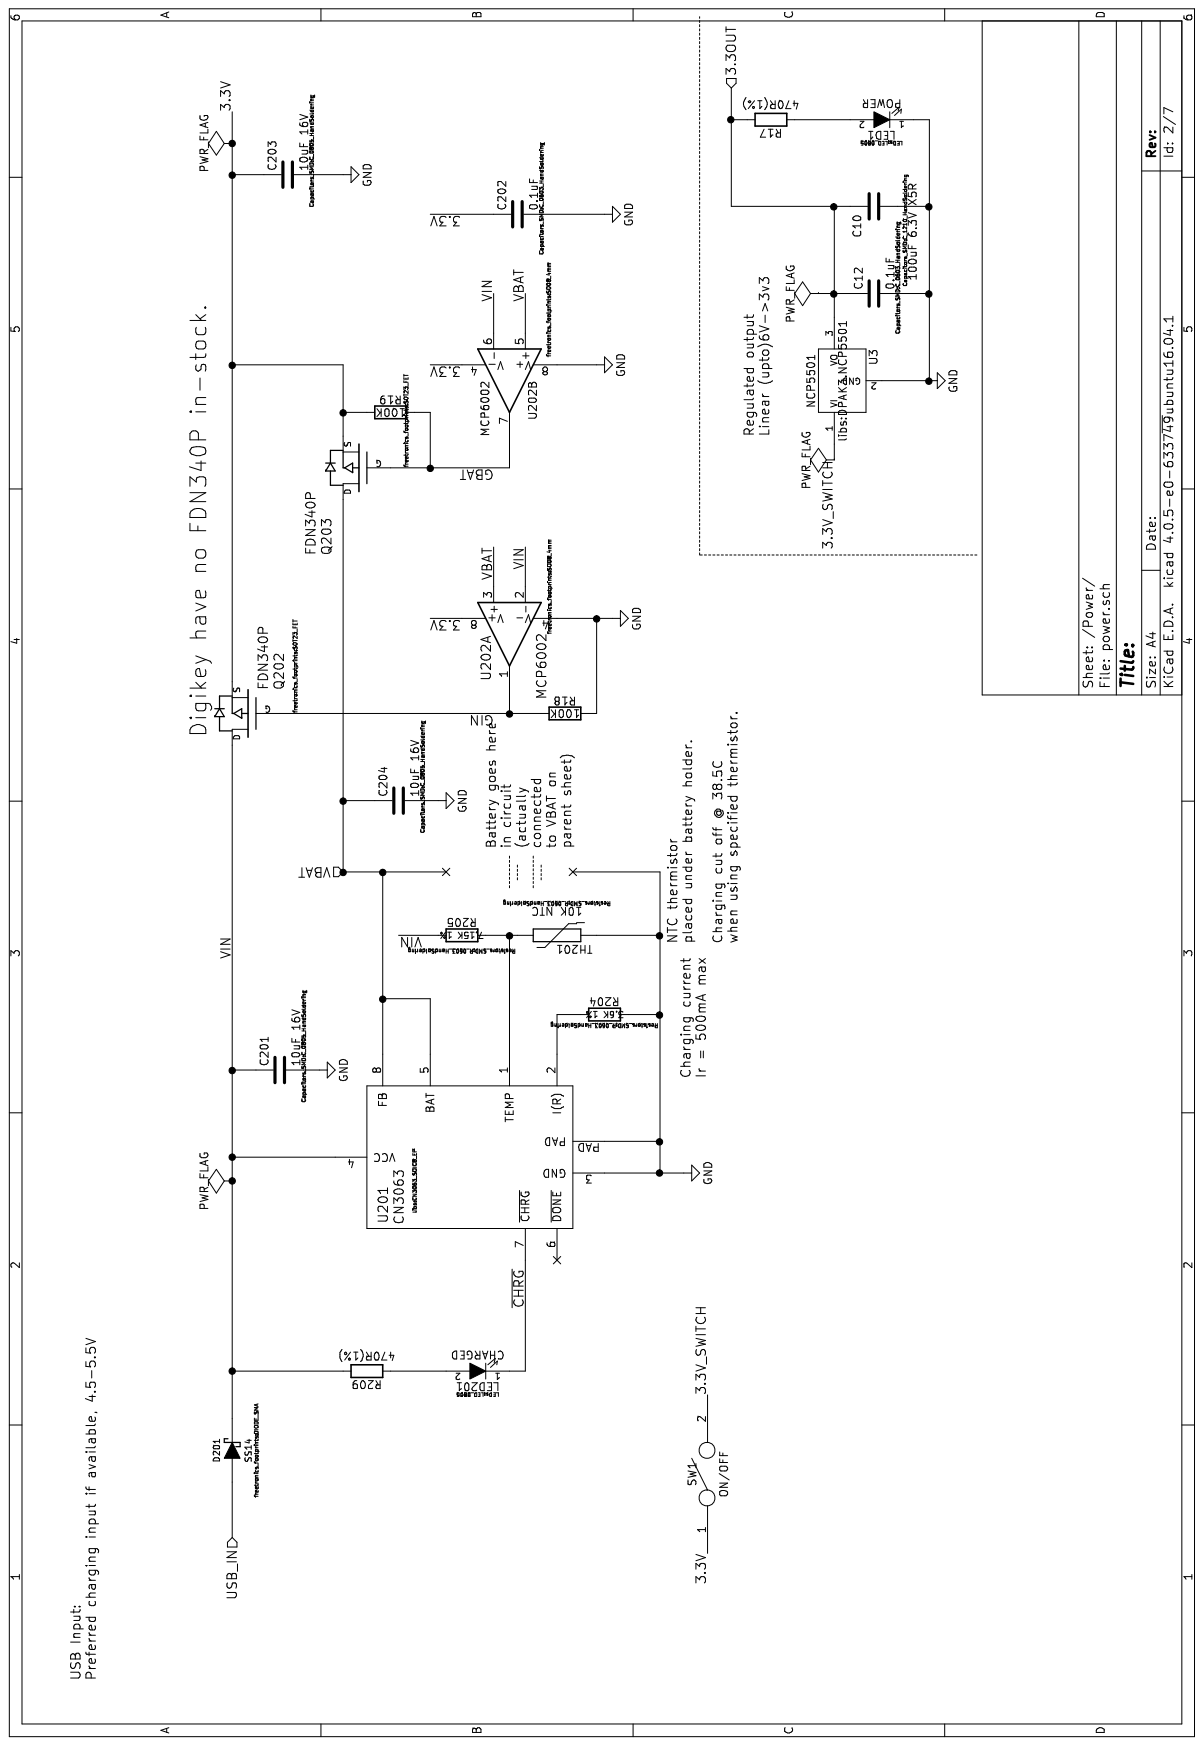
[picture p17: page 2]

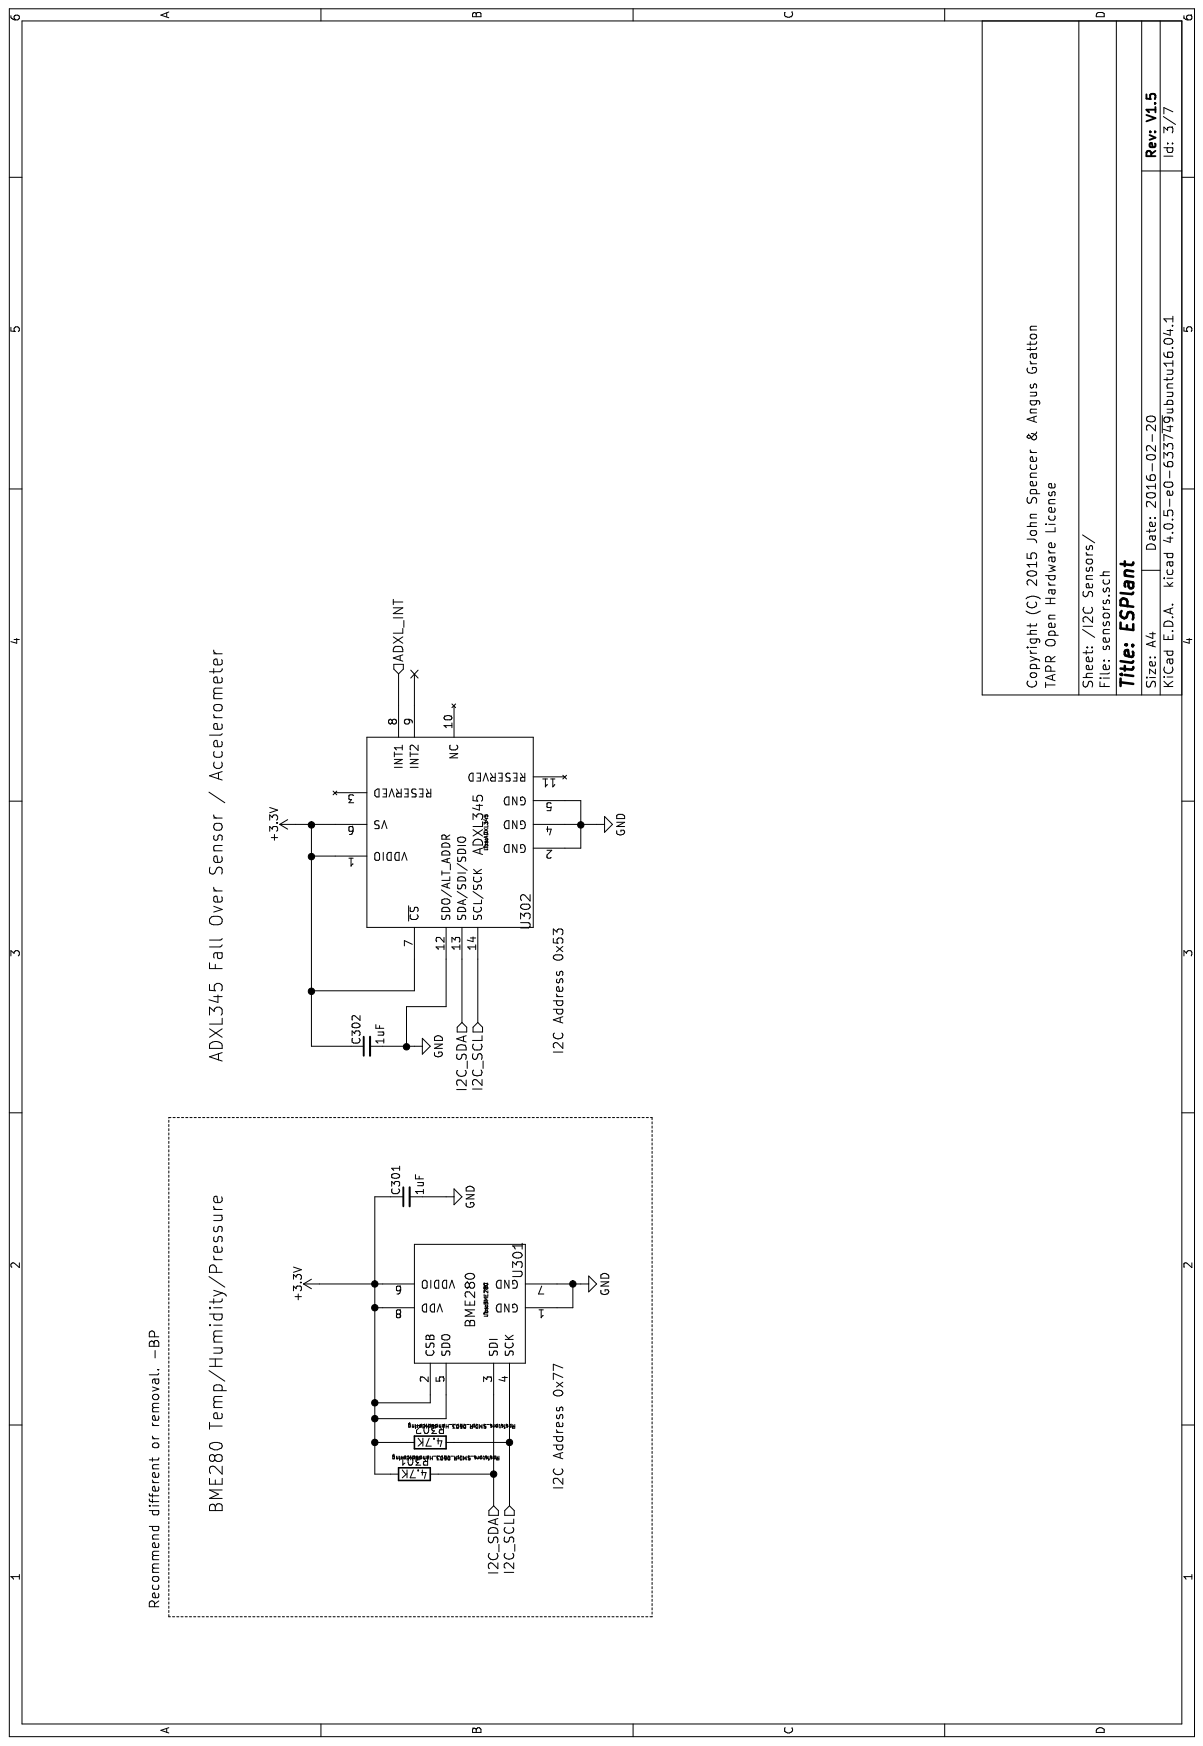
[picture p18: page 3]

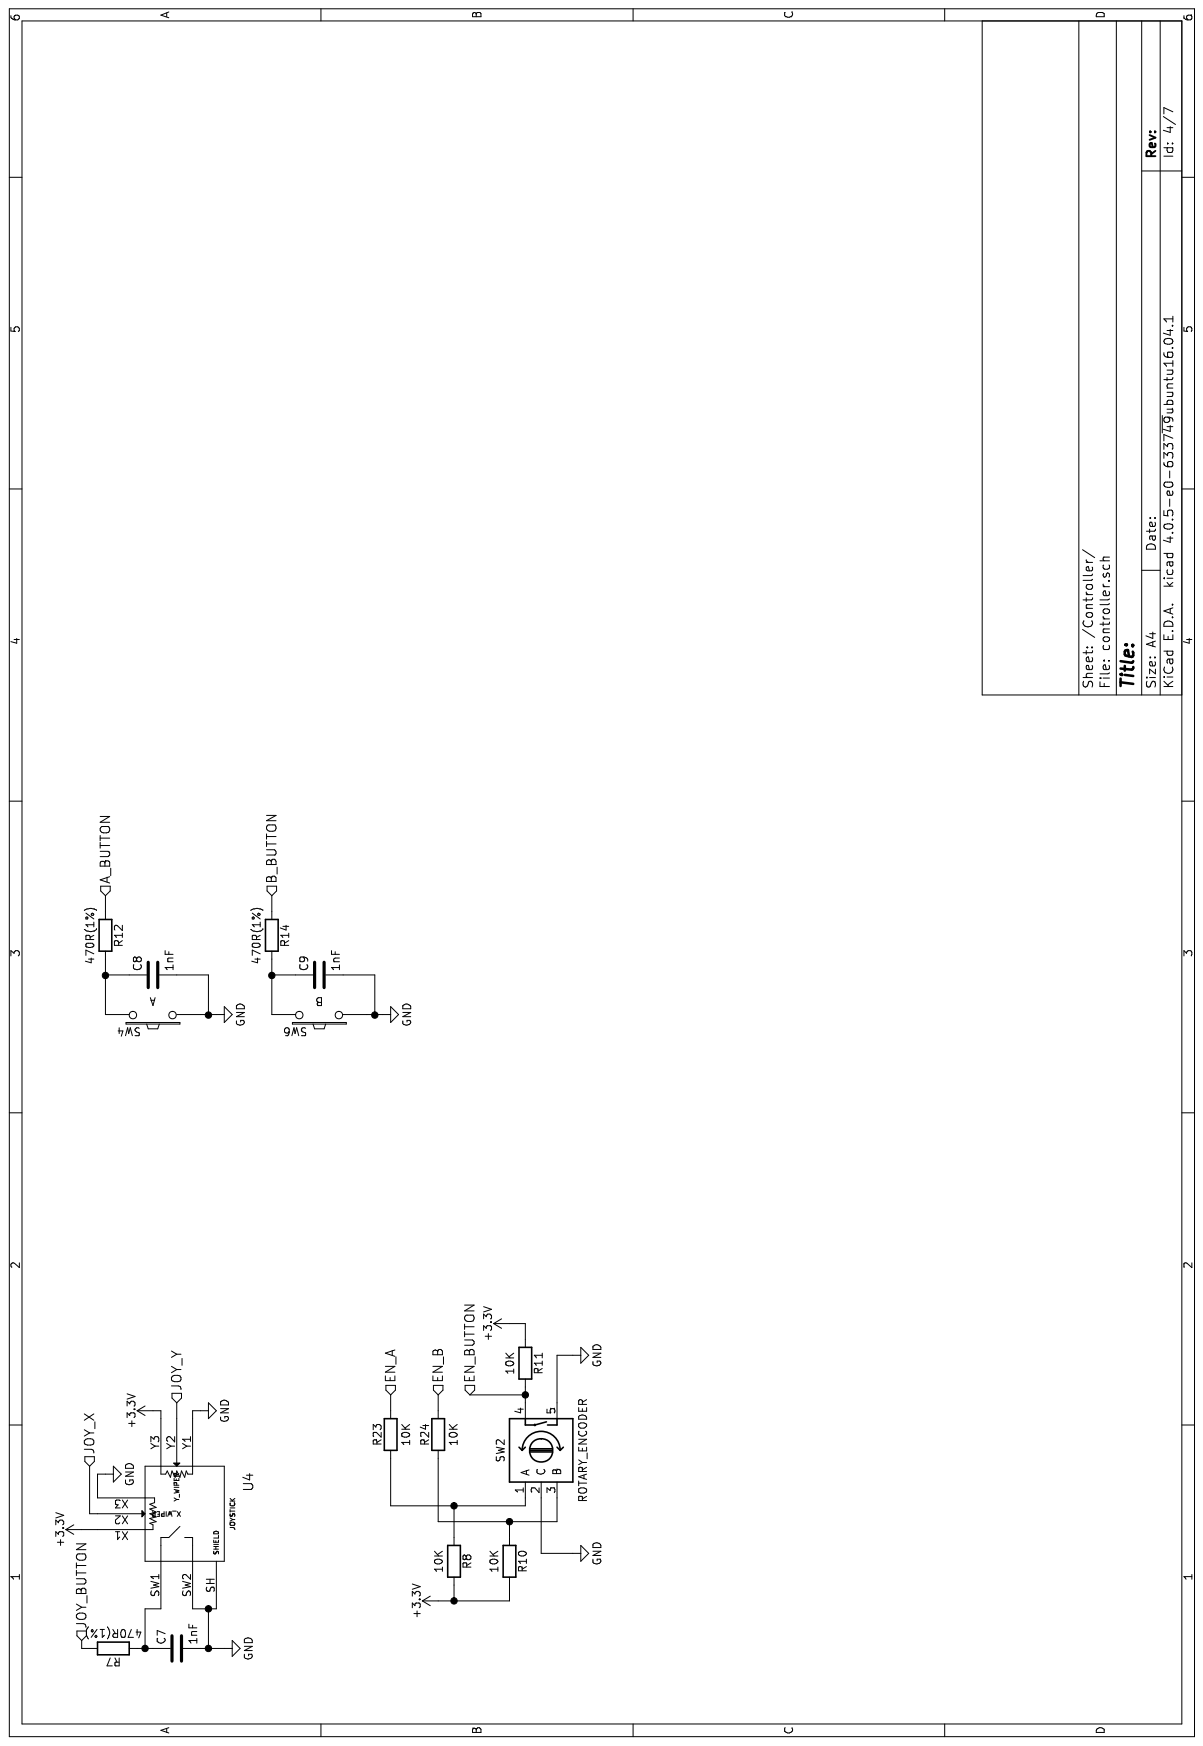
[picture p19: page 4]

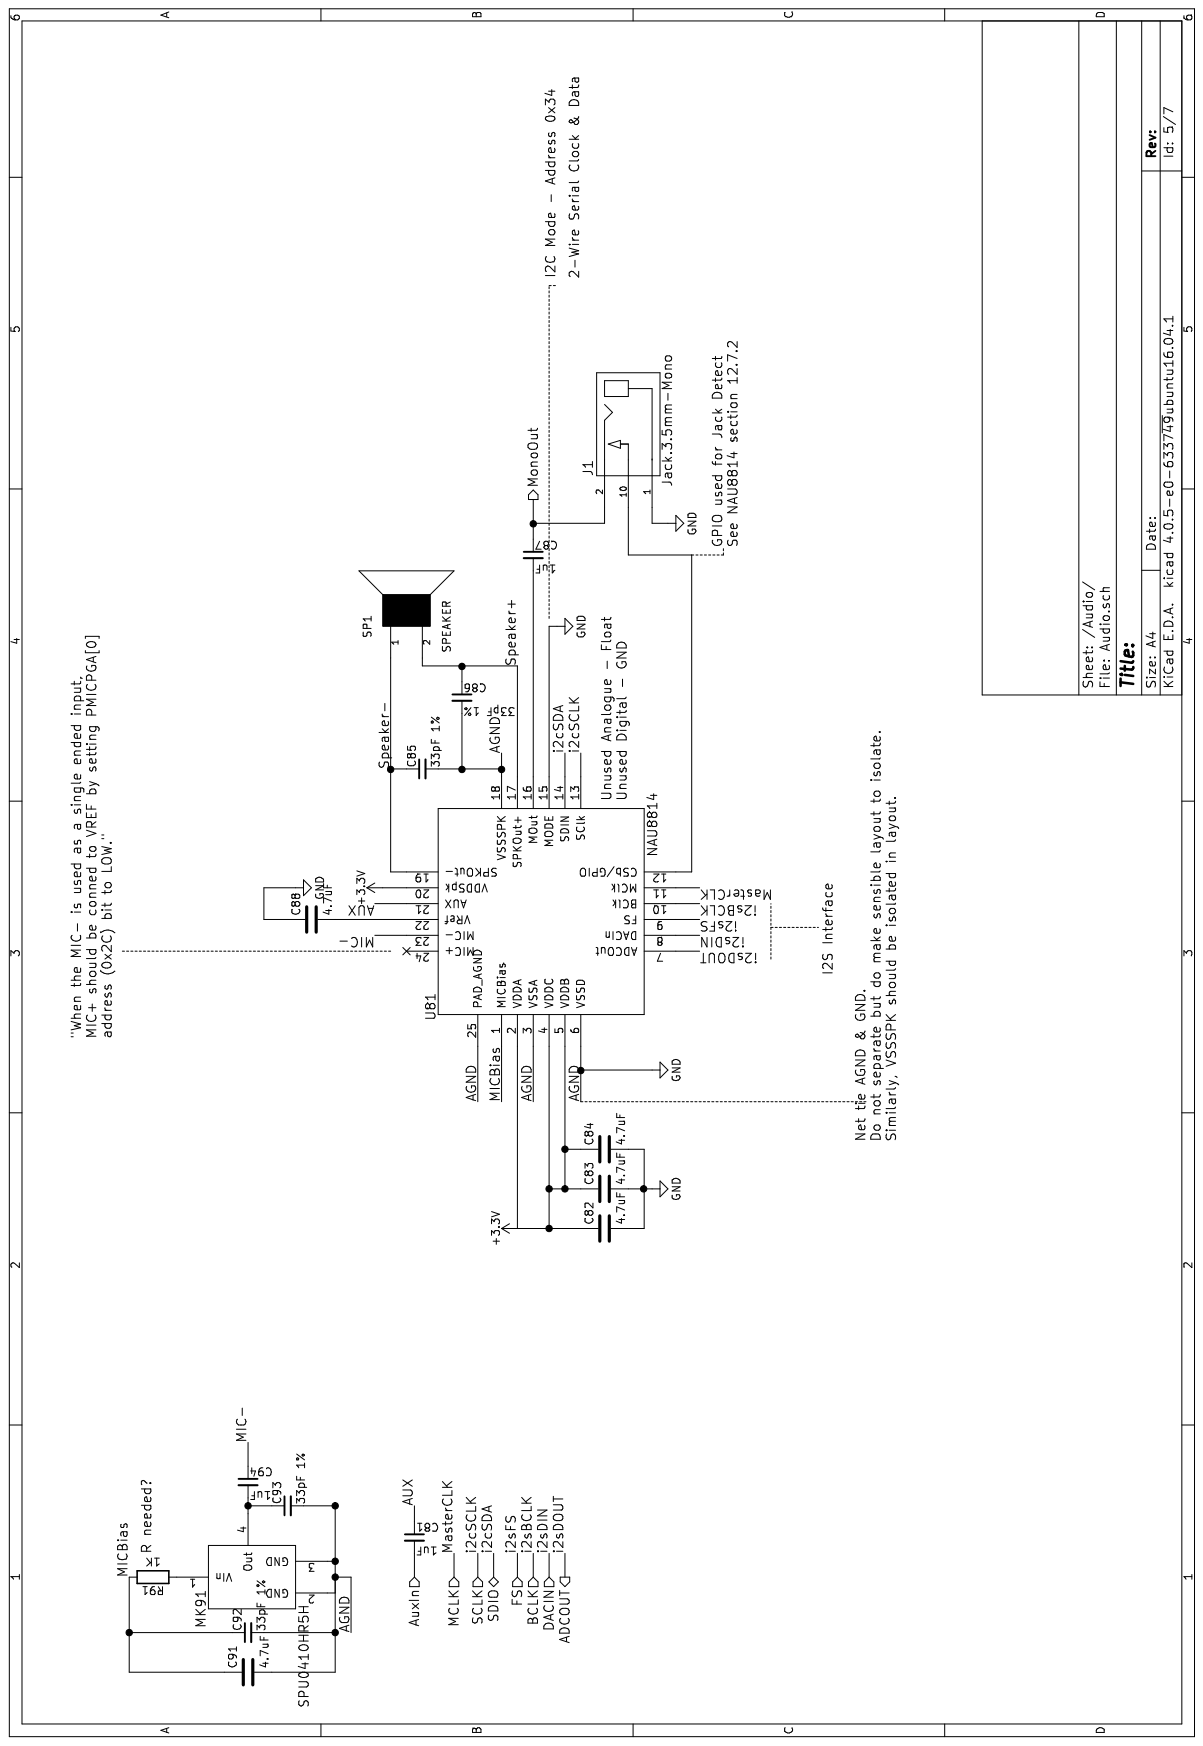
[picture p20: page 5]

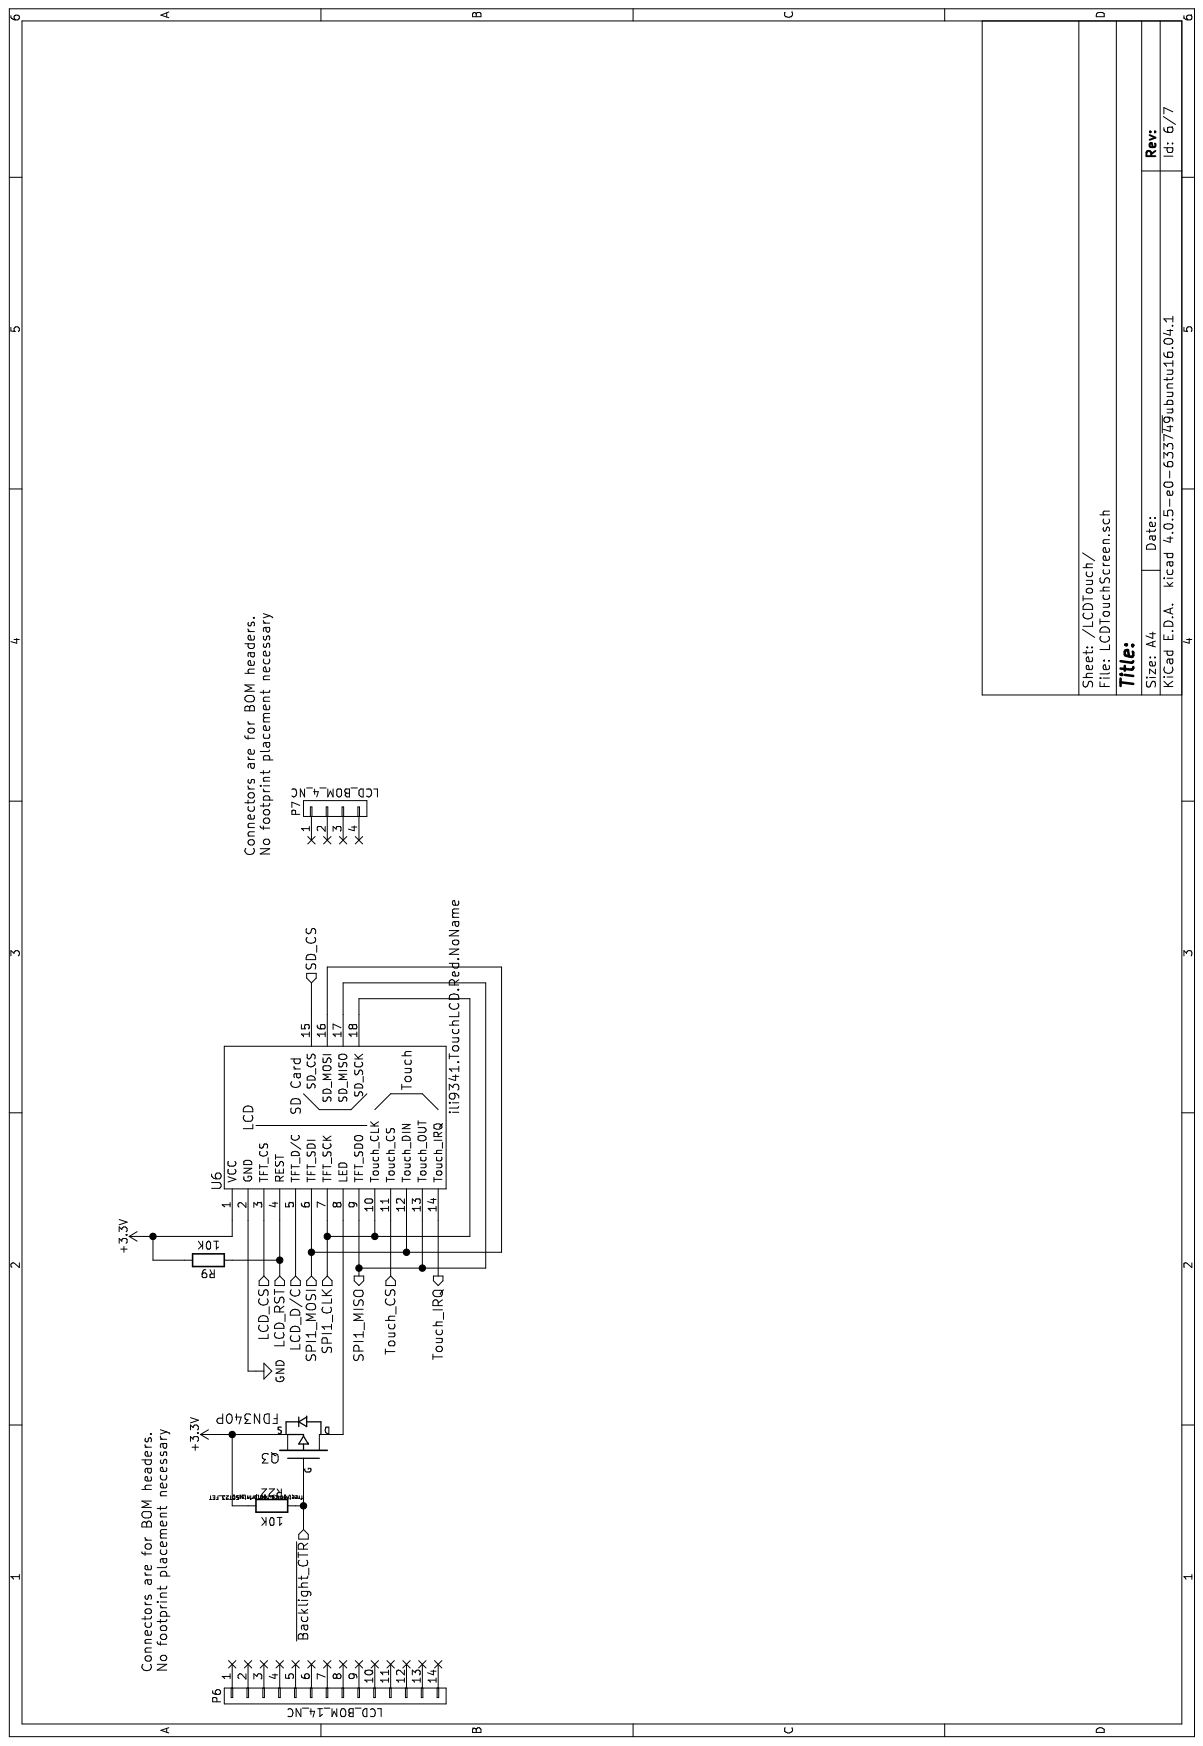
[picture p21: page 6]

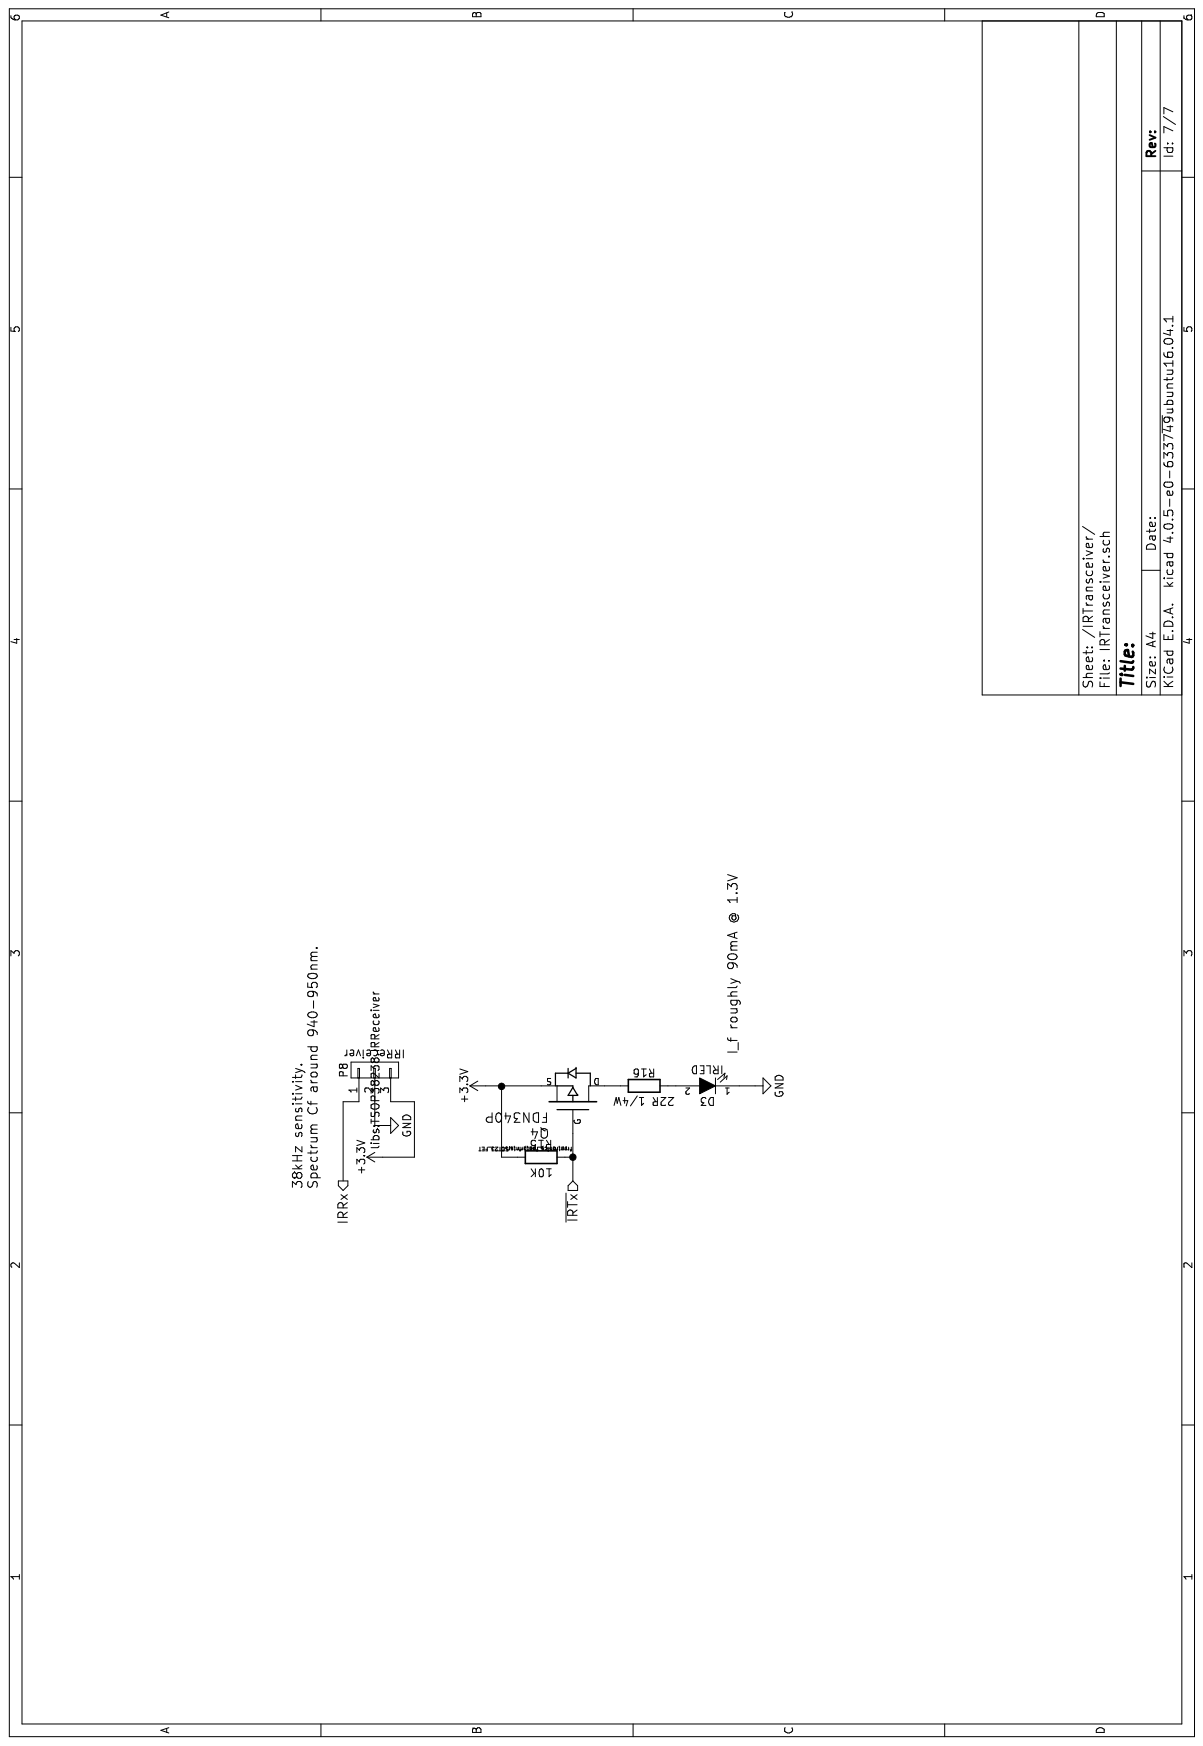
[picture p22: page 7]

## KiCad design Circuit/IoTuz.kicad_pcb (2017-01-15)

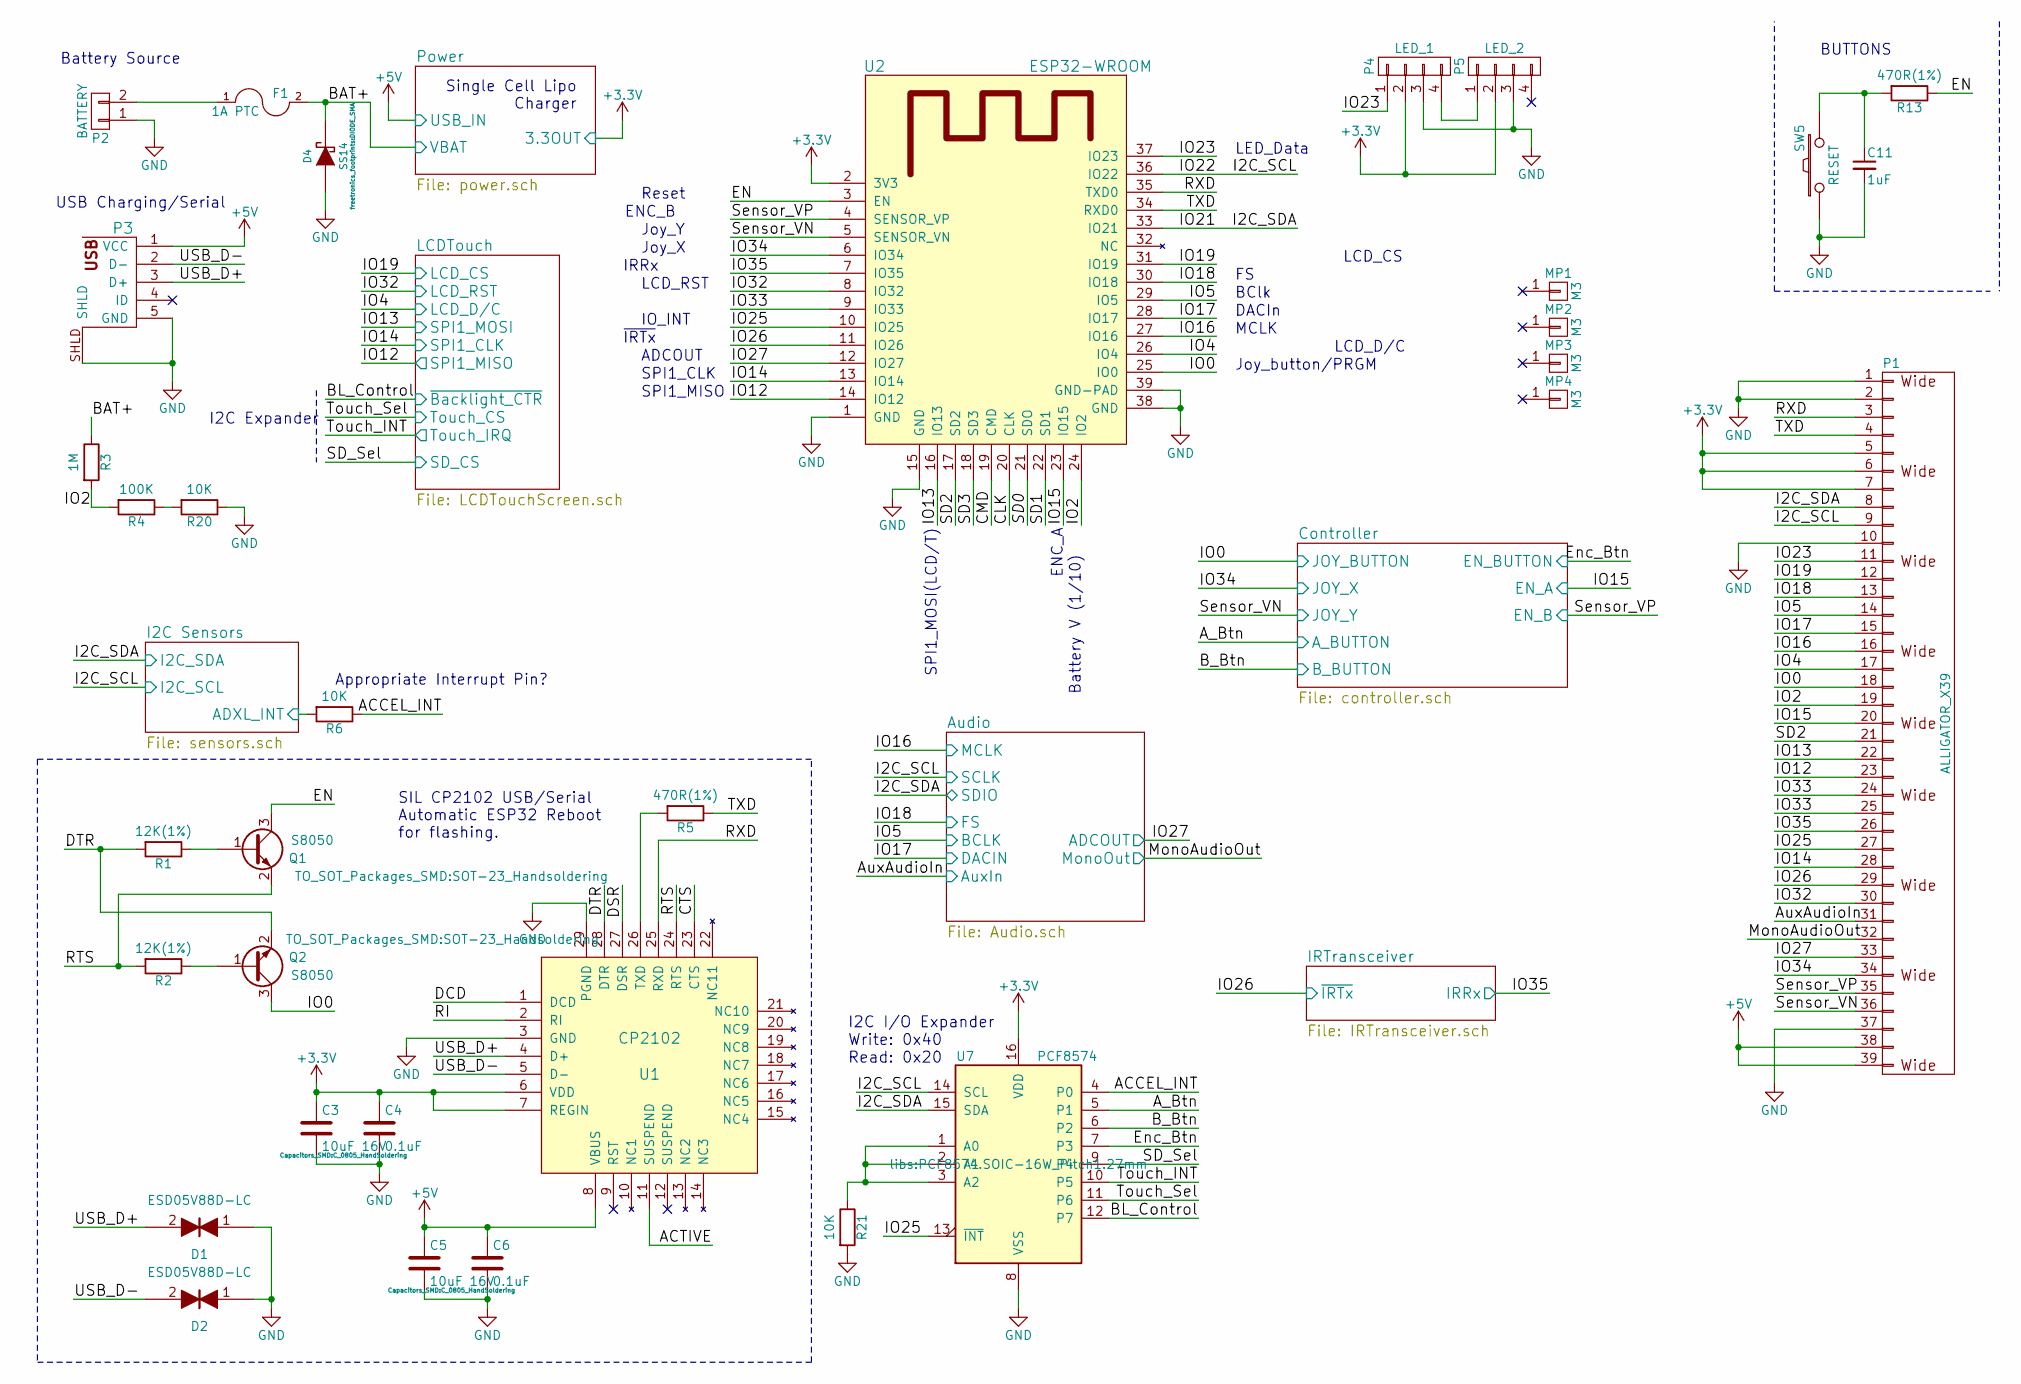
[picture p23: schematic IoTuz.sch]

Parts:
C3, C5: 10uF 16V; C_0805_HandSoldering; Manufacturer PN CL21A106KOCLRNC; Digikey PN 1276-2399-1-ND
C4, C6: 0.1uF; C_0603_HandSoldering; Manufacturer PN CC0603KRX7R7BB104; Digikey PN 311-1088-1-ND
C11: 1uF; C_0603_HandSoldering; Manufacturer PN GRM188R61C105KA93D; Digikey PN 490-1536-1-ND
D1, D2: ESD05V88D-LC; SOD-882
D4: SS14; DIODE_SMA; Manufacturer PN SS14; Digikey PN SS14CT-ND
F1: 1A PTC; 1210; Manufacturer PN 0ZCH0050FF2G; Digikey PN 507-1786-1-ND
MP1, MP2, MP3, MP4: M3; MountingHole_3.2mm_M3.IoTuz
P1: ALLIGATOR_X39; alligator_pads.x39.shortened
P2: BATTERY; BH-18650
P3: USB_5PIN_SHELL; USB-MICRO-5pin_PTHMOUNT-Amphenol.10118194-0001LF; Manufacturer PN 10118194-0001LF; Digikey PN 609-4618-1-ND
P4: LED_1; LED_8MM_APA-106
P5: LED_2; LED_8MM_APA-106
Q1, Q2: S8050; SOT-23_Handsoldering; Manufacturer PN MMSS8050-H-TP; Digikey PN MMSS8050-H-TPMSCT-ND
R1, R2: 12K(1%); R_0603_HandSoldering; Manufacturer PN RC0603FR-0712KL; Digikey PN 311-12.0KHRCT-ND
R3: 1M; R_0603_HandSoldering; Manufacturer PN RC0603FR-071ML; Digikey PN 311-1.00MHRCT-ND
R4: 100K; R_0603_HandSoldering; Manufacturer PN RC0603JR-07100KL; Digikey PN 311-100KGRCT-ND
R5, R13: 470R(1%); R_0603_HandSoldering; Manufacturer PN RC0603FR-07470RL; Digikey PN 311-470HRCT-ND
R6, R20, R21: 10K; R_0603_HandSoldering; Manufacturer PN RC0603JR-0710KL; Digikey PN 311-10KGRCT-ND
SW5: RESET; SW_PUSHBUTTON_PTH
U1: CP2102; QFN-28-1EP_5x5mm_Pitch0.5mm; Manufacturer PN CP2102-GMR; Digikey PN 336-1160-1-ND
U2: ESP32-WROOM
U7: PCF8574; PCF8574.SOIC-16W_Pitch1.27mm; Manufacturer PN PCF8574T/3,518; Digikey PN 568-1077-1-ND

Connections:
+3V3: C3.1, C4.1, P1.5, P1.6, P1.7, P4.2, P5.2, U1.6 (VDD), U1.7 (REGIN), U2.2 (3V3), U7.16 (VDD); also elsewhere on the board
+5V: C5.1, C6.1, P1.38, P1.39, P3.1 (VCC), U1.8 (VBUS); also elsewhere on the board
/ACCEL_INT: R6.1, U7.4 (P0)
/ACTIVE: U1.11 (SUSPEND)
/A_Btn: U7.5 (P1); also elsewhere on the board
/AuxAudioIn: P1.31; also elsewhere on the board
/BAT+: D4.K, F1.2, R3.1; also elsewhere on the board
/BL_Control: U7.12 (P7); also elsewhere on the board
/B_Btn: U7.6 (P2); also elsewhere on the board
/CLK: U2.20 (CLK)
/CMD: U2.19 (CMD)
/CTS: U1.23 (CTS)
/DCD: U1.1 (DCD)
/DSR: U1.27 (DSR)
/DTR: Q2.2 (E), R1.2, U1.28 (DTR)
/EN: Q1.3 (C), R13.1, U2.3 (EN)
/Enc_Btn: U7.7 (P3); also elsewhere on the board
/I2C Sensors/ADXL_INT: R6.2; also elsewhere on the board
/I2C_SCL: P1.9, U2.36 (IO22), U7.14 (SCL); also elsewhere on the board
/I2C_SDA: P1.8, U2.33 (IO21), U7.15 (SDA); also elsewhere on the board
/IO0: P1.18, Q2.3 (C), U2.25 (IO0); also elsewhere on the board
/IO2: P1.19, R3.2, R4.2, U2.24 (IO2)
/IO4: P1.17, U2.26 (IO4); also elsewhere on the board
/IO5: P1.14, U2.29 (IO5); also elsewhere on the board
/IO12: P1.23, U2.14 (IO12); also elsewhere on the board
/IO13: P1.22, U2.16 (IO13); also elsewhere on the board
/IO14: P1.28, U2.13 (IO14); also elsewhere on the board
/IO15: P1.20, U2.23 (IO15); also elsewhere on the board
/IO16: P1.16, U2.27 (IO16); also elsewhere on the board
/IO17: P1.15, U2.28 (IO17); also elsewhere on the board
/IO18: P1.13, U2.30 (IO18); also elsewhere on the board
/IO19: P1.12, U2.31 (IO19); also elsewhere on the board
/IO23: P1.11, P4.1, U2.37 (IO23)
/IO25: P1.27, U2.10 (IO25), U7.13 (~INT~)
/IO26: P1.29, U2.11 (IO26); also elsewhere on the board
/IO27: P1.33, U2.12 (IO27); also elsewhere on the board
/IO32: P1.30, U2.8 (IO32); also elsewhere on the board
/IO33: P1.24, P1.25, U2.9 (IO33)
/IO34: P1.34, U2.6 (IO34); also elsewhere on the board
/IO35: P1.26, U2.7 (IO35); also elsewhere on the board
/MonoAudioOut: P1.32; also elsewhere on the board
/RI: U1.2 (RI)
/RTS: Q1.2 (E), R2.2, U1.24 (RTS)
/RXD: P1.3, U1.25 (RXD), U2.35 (TXD0)
/SD0: U2.21 (SDO)
/SD1: U2.22 (SD1)
/SD2: P1.21, U2.17 (SD2)
/SD3: U2.18 (SD3)
/SD_Sel: U7.9 (P4); also elsewhere on the board
/Sensor_VN: P1.36, U2.5 (SENSOR_VN); also elsewhere on the board
/Sensor_VP: P1.35, U2.4 (SENSOR_VP); also elsewhere on the board
/TXD: P1.4, R5.1, U2.34 (RXD0)
/Touch_INT: U7.10 (P5); also elsewhere on the board
/Touch_Sel: U7.11 (P6); also elsewhere on the board
/USB_D+: D1.2, P3.3 (D+), U1.4 (D+)
/USB_D-: D2.2, P3.2 (D-), U1.5 (D-)
unnamed: C11.1, R13.2, SW5.2
unnamed: F1.1, P2.2
unnamed: P4.4, P5.1
unnamed: Q1.1 (B), R1.1
unnamed: Q2.1 (B), R2.1
unnamed: R5.2, U1.26 (TXD)
unnamed: R4.1, R20.2
unnamed: R21.1, U7.1 (A0), U7.2 (A1), U7.3 (A2)

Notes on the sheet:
USB Charging/Serial
Battery Source
Single Cell Lipo Charger
SIL CP2102 USB/Serial Automatic ESP32 Reboot for flashing.
BUTTONS
Joy_button/PRGM
ENC_A
ENC_B
Joy_X
Battery V (1/10)
Reset
MCLK
Appropriate Interrupt Pin?
~IRTx
LED_Data
LCD_CS
LCD_RST
LCD_D/C
SPI1_CLK
SPI1_MISO
I2C I/O Expander Write: 0x40 Read: 0x20
I2C Expander
IO_INT
IRRx
Joy_Y
ADCOUT
DACIn
BClk
SPI1_MOSI(LCD/T)

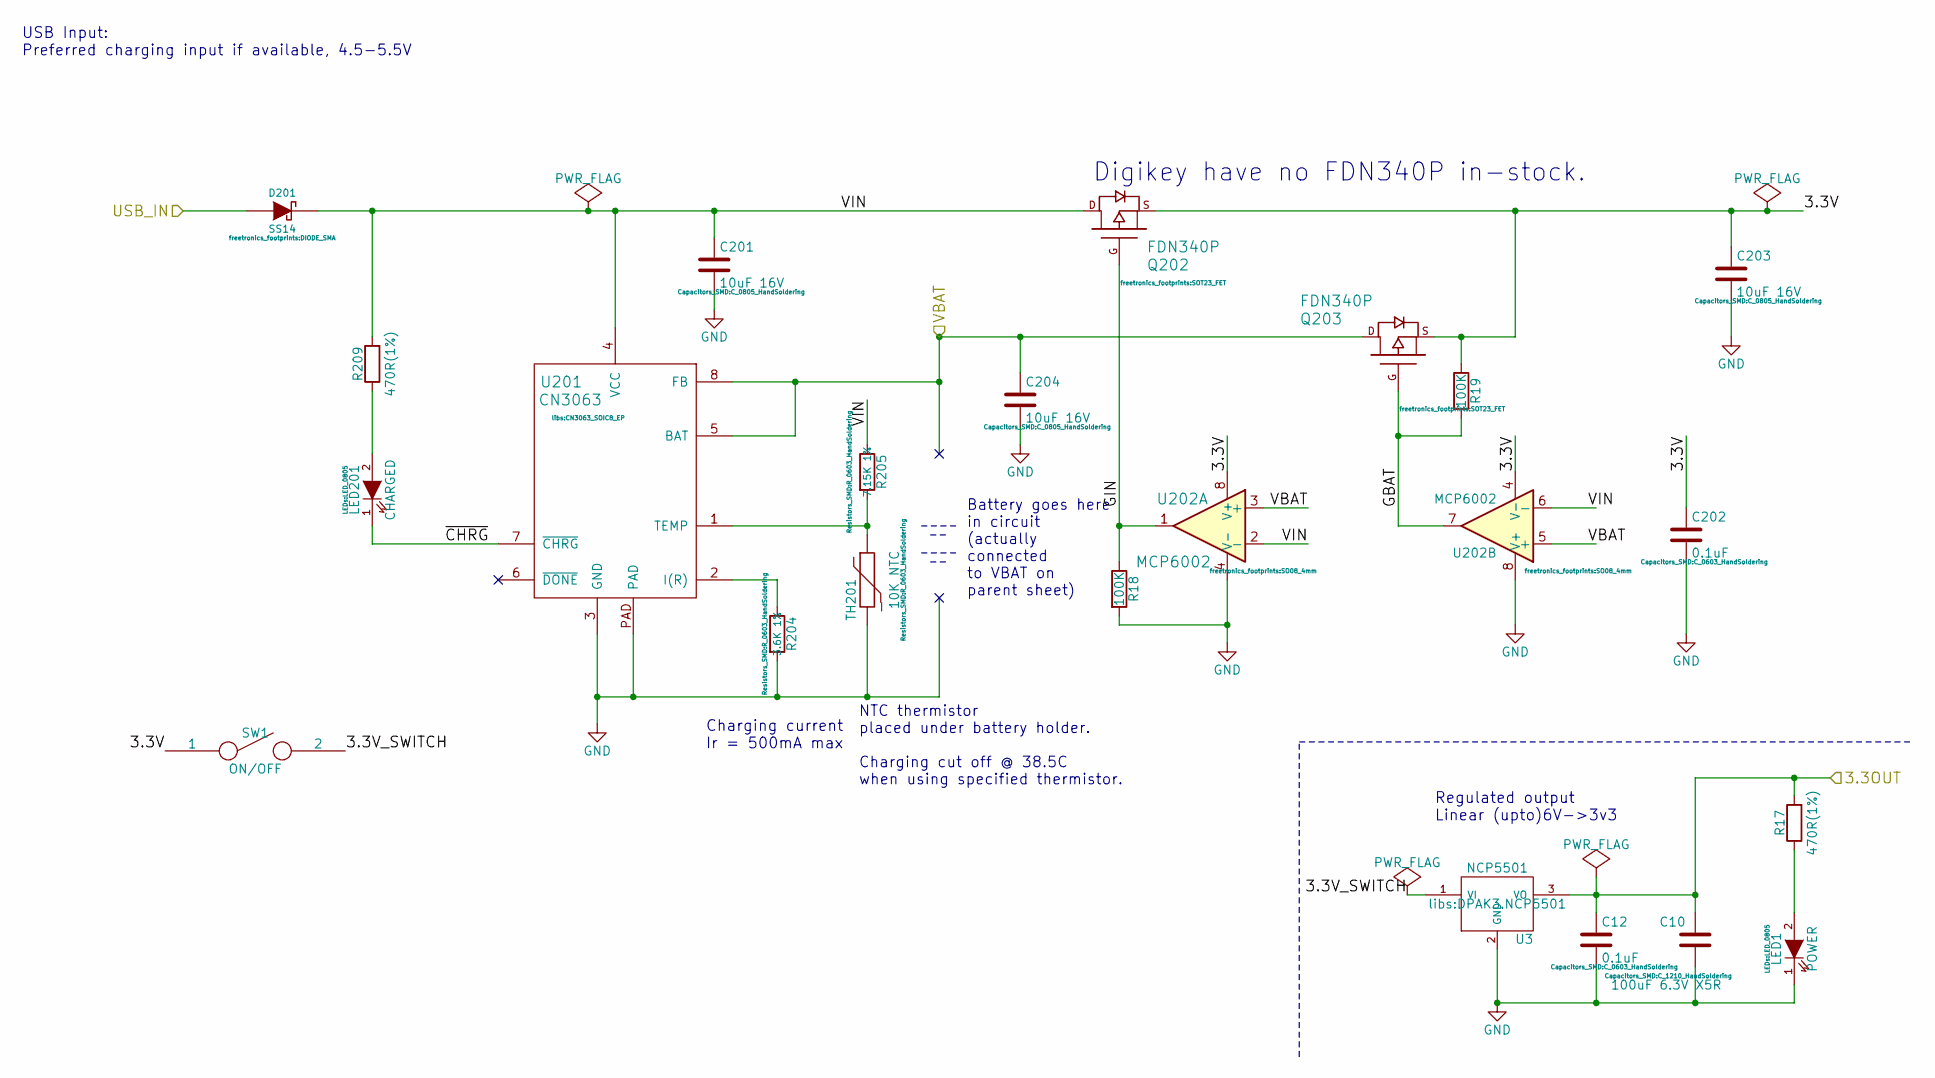
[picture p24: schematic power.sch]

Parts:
C10: 100uF 6.3V X5R; C_1210_HandSoldering; Manufacturer PN GRM31CR60J107ME39K; Digikey PN 490-7217-1-ND
C12, C202: 0.1uF; C_0603_HandSoldering; Manufacturer PN CC0603KRX7R7BB104; Digikey PN 311-1088-1-ND
C201, C203, C204: 10uF 16V; C_0805_HandSoldering; Manufacturer PN CL21A106KOCLRNC; Digikey PN 1276-2399-1-ND
D201: SS14; DIODE_SMA; Manufacturer PN SS14; Digikey PN SS14CT-ND
LED1: POWER; LED_0805; Manufacturer PN 150080RS75000; Digikey PN 732-4984-1-ND
LED201: CHARGED; LED_0805; Manufacturer PN LTST-C170KFKT; Digikey PN 160-1413-1-ND
Q202, Q203: FDN340P; SOT23_FET; Manufacturer PN FDN340P; Digikey PN FDN340PCT-ND
R17, R209: 470R(1%); R_0603_HandSoldering; Manufacturer PN RC0603FR-07470RL; Digikey PN 311-470HRCT-ND
R18, R19: 100K; R_0603_HandSoldering; Manufacturer PN RC0603JR-07100KL; Digikey PN 311-100KGRCT-ND
R204: 3.6K 1%; R_0603_HandSoldering; Manufacturer PN RC0603FR-073K6L; Digikey PN 311-3.60KHRCT-ND
R205: 7.15K 1%; R_0603_HandSoldering; Manufacturer PN RC0603FR-077K15L; Digikey PN 311-7.15KHRCT-ND
SW1: ON/OFF; SS12D00
TH201: 10K NTC; R_0603_HandSoldering; Manufacturer PN NCP18XH103F03RB; Digikey PN 490-4800-1-ND
U3: NCP5501; DPAK3.NCP5501; Manufacturer PN NCP5501DT33RKG; Digikey PN NCP5501DT33RKGOSCT-ND
U201: CN3063; CN3063_SOIC8_EP
U202: MCP6002; SO08_4mm; Manufacturer PN MCP6002T-I/SN; Digikey PN MCP6002T-I/SNCT-ND

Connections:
+3V3: C10.2, C12.1, R17.2, U3.3 (VO); also elsewhere on the board
+5V: D201.A; also elsewhere on the board
/BAT+: C204.1, Q203.D, U201.5 (BAT), U201.8 (FB), U202.3 (+), U202.5 (+); also elsewhere on the board
/Power/3.3V_SWITCH: SW1.2, U3.1 (VI)
/Power/GBAT: Q203.G, R19.2, U202.7
/Power/GIN: Q202.G, R18.1, U202.1
/Power/VIN: C201.1, D201.K, Q202.D, R205.1, R209.2, U201.4 (VCC), U202.2 (-), U202.6 (-)
/Power/~CHRG: LED201.1 (K), U201.7 (~CHRG)
unnamed: LED1.2 (A), R17.1
unnamed: LED201.2 (A), R209.1
unnamed: R204.1, U201.2 (I(R))
unnamed: R205.2, TH201.1, U201.1 (TEMP)

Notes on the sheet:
USB Input: Preferred charging input if available, 4.5-5.5V
Charging current Ir = 500mA max
Battery goes here in circuit (actually connected to VBAT on parent sheet)
NTC thermistor placed under battery holder. Charging cut off @ 38.5C when using specified thermistor.
Regulated output Linear (upto)6V->3v3
Digikey have no FDN340P in-stock.

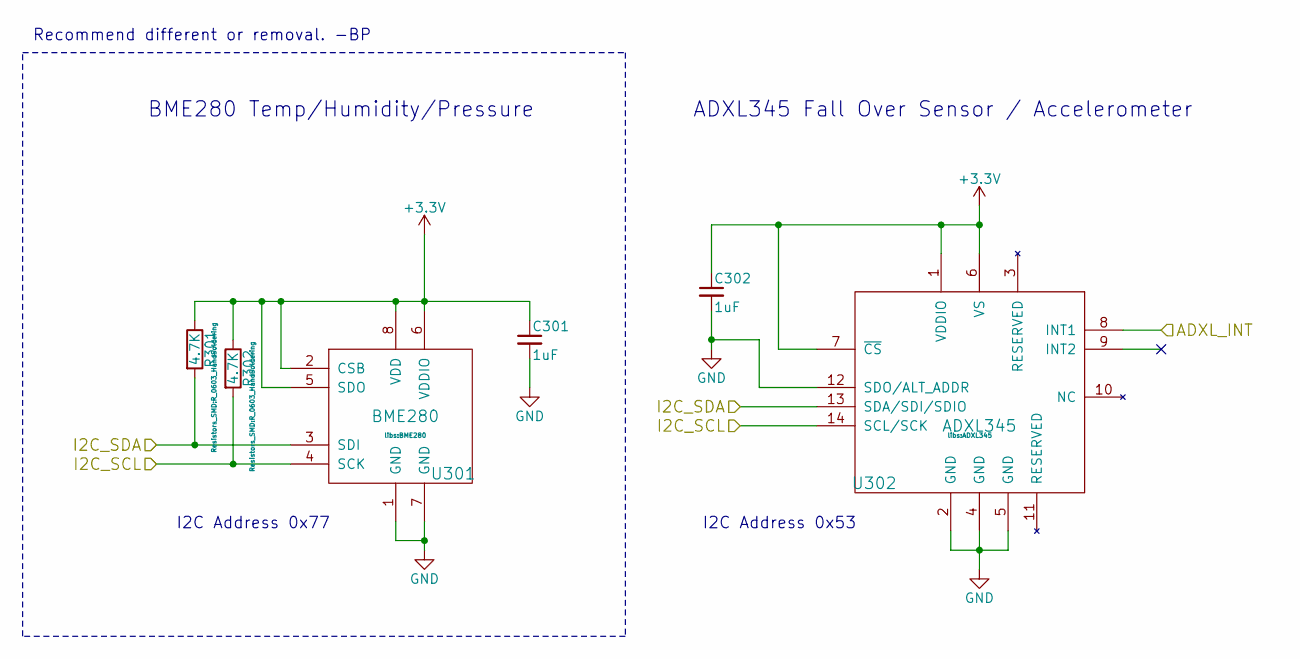
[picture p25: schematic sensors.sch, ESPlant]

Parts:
C301, C302: 1uF; C_0603_HandSoldering; Manufacturer PN GRM188R61C105KA93D; Digikey PN 490-1536-1-ND
R301, R302: 4.7K; R_0603_HandSoldering; Manufacturer PN RC0603JR-074K7L; Digikey PN 311-4.7KGRCT-ND
U301: BME280; Manufacturer PN BME280; Digikey PN 828-1063-1-ND
U302: ADXL345; Manufacturer PN ADXL345BCCZ-RL; Digikey PN ADXL345BCCZ-RLCT-ND

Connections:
+3V3: C301.1, C302.1, R301.1, R302.1, U301.2 (CSB), U301.5 (SDO), U301.6 (VDDIO), U301.8 (VDD), U302.1 (VDDIO), U302.6 (VS), U302.7 (~CS); also elsewhere on the board
/I2C Sensors/ADXL_INT: U302.8 (INT1); also elsewhere on the board
/I2C_SCL: R302.2, U301.4 (SCK), U302.14 (SCL/SCK); also elsewhere on the board
/I2C_SDA: R301.2, U301.3 (SDI), U302.13 (SDA/SDI/SDIO); also elsewhere on the board

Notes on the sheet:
I2C Address 0x77
BME280 Temp/Humidity/Pressure
I2C Address 0x53
ADXL345 Fall Over Sensor / Accelerometer
Recommend different or removal. -BP

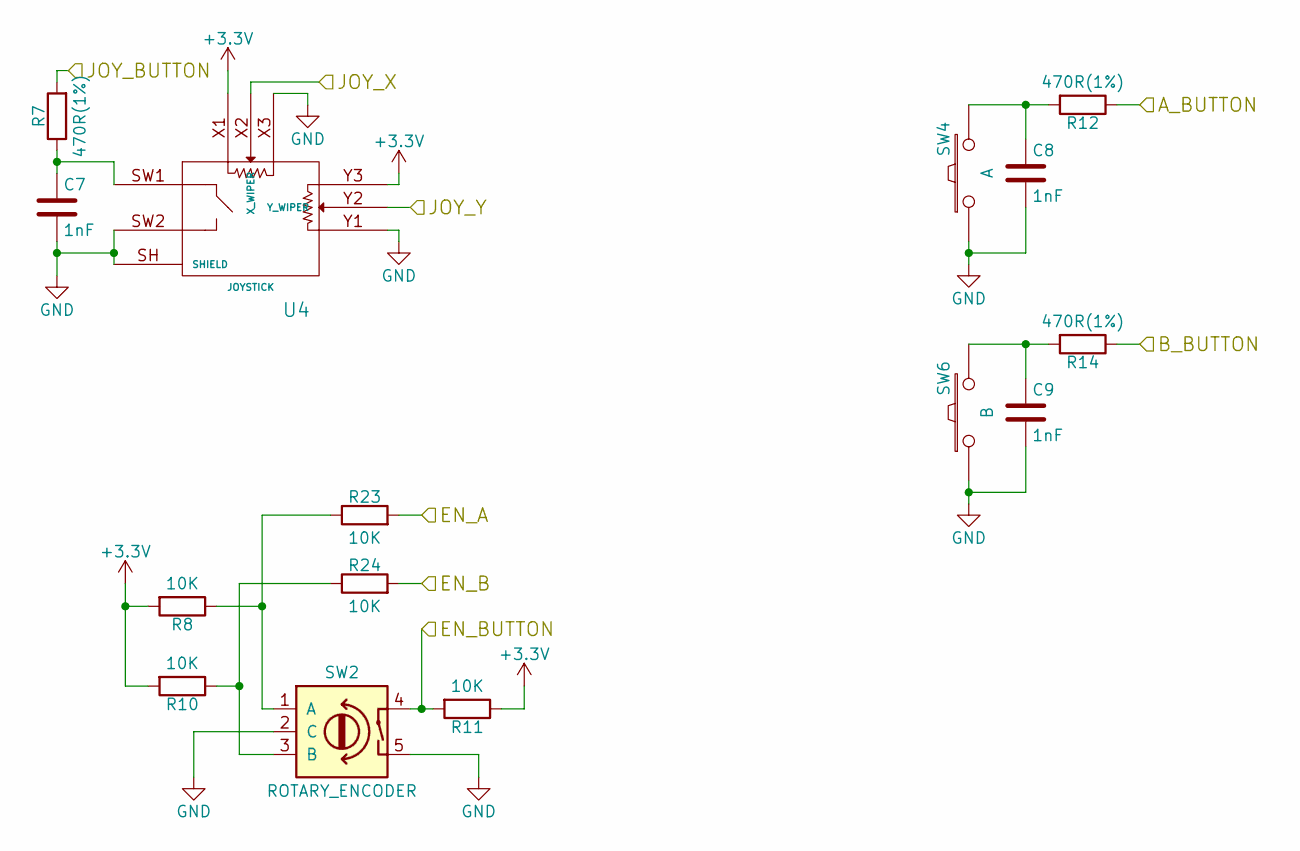
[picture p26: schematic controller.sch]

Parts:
C7, C8, C9: 1nF; C_0603_HandSoldering; Manufacturer PN GRM188R71H102KA01D; Digikey PN 490-1494-1-ND
R7, R12, R14: 470R(1%); R_0603_HandSoldering; Manufacturer PN RC0603FR-07470RL; Digikey PN 311-470HRCT-ND
R8, R10, R11, R23, R24: 10K; R_0603_HandSoldering; Manufacturer PN RC0603JR-0710KL; Digikey PN 311-10KGRCT-ND
SW2: ROTARY_ENCODER; EC11
SW4: A; SW_PUSHBUTTON_PTH
SW6: B; SW_PUSHBUTTON_PTH
U4: JOYSTICK; JOYSTICK_W_BUTTON

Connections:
+3V3: R8.2, R10.2, R11.1, U4.X1, U4.Y3; also elsewhere on the board
/A_Btn: R12.1; also elsewhere on the board
/B_Btn: R14.1; also elsewhere on the board
/Enc_Btn: R11.2, SW2.4; also elsewhere on the board
/IO0: R7.2; also elsewhere on the board
/IO15: R23.2; also elsewhere on the board
/IO34: U4.X2 (X_WIPER); also elsewhere on the board
/Sensor_VN: U4.Y2 (Y_WIPER); also elsewhere on the board
/Sensor_VP: R24.2; also elsewhere on the board
unnamed: C7.1, R7.1, U4.SW1
unnamed: C8.1, R12.2, SW4.2
unnamed: C9.1, R14.2, SW6.2
unnamed: R10.1, R24.1, SW2.3 (B)
unnamed: R8.1, R23.1, SW2.1 (A)

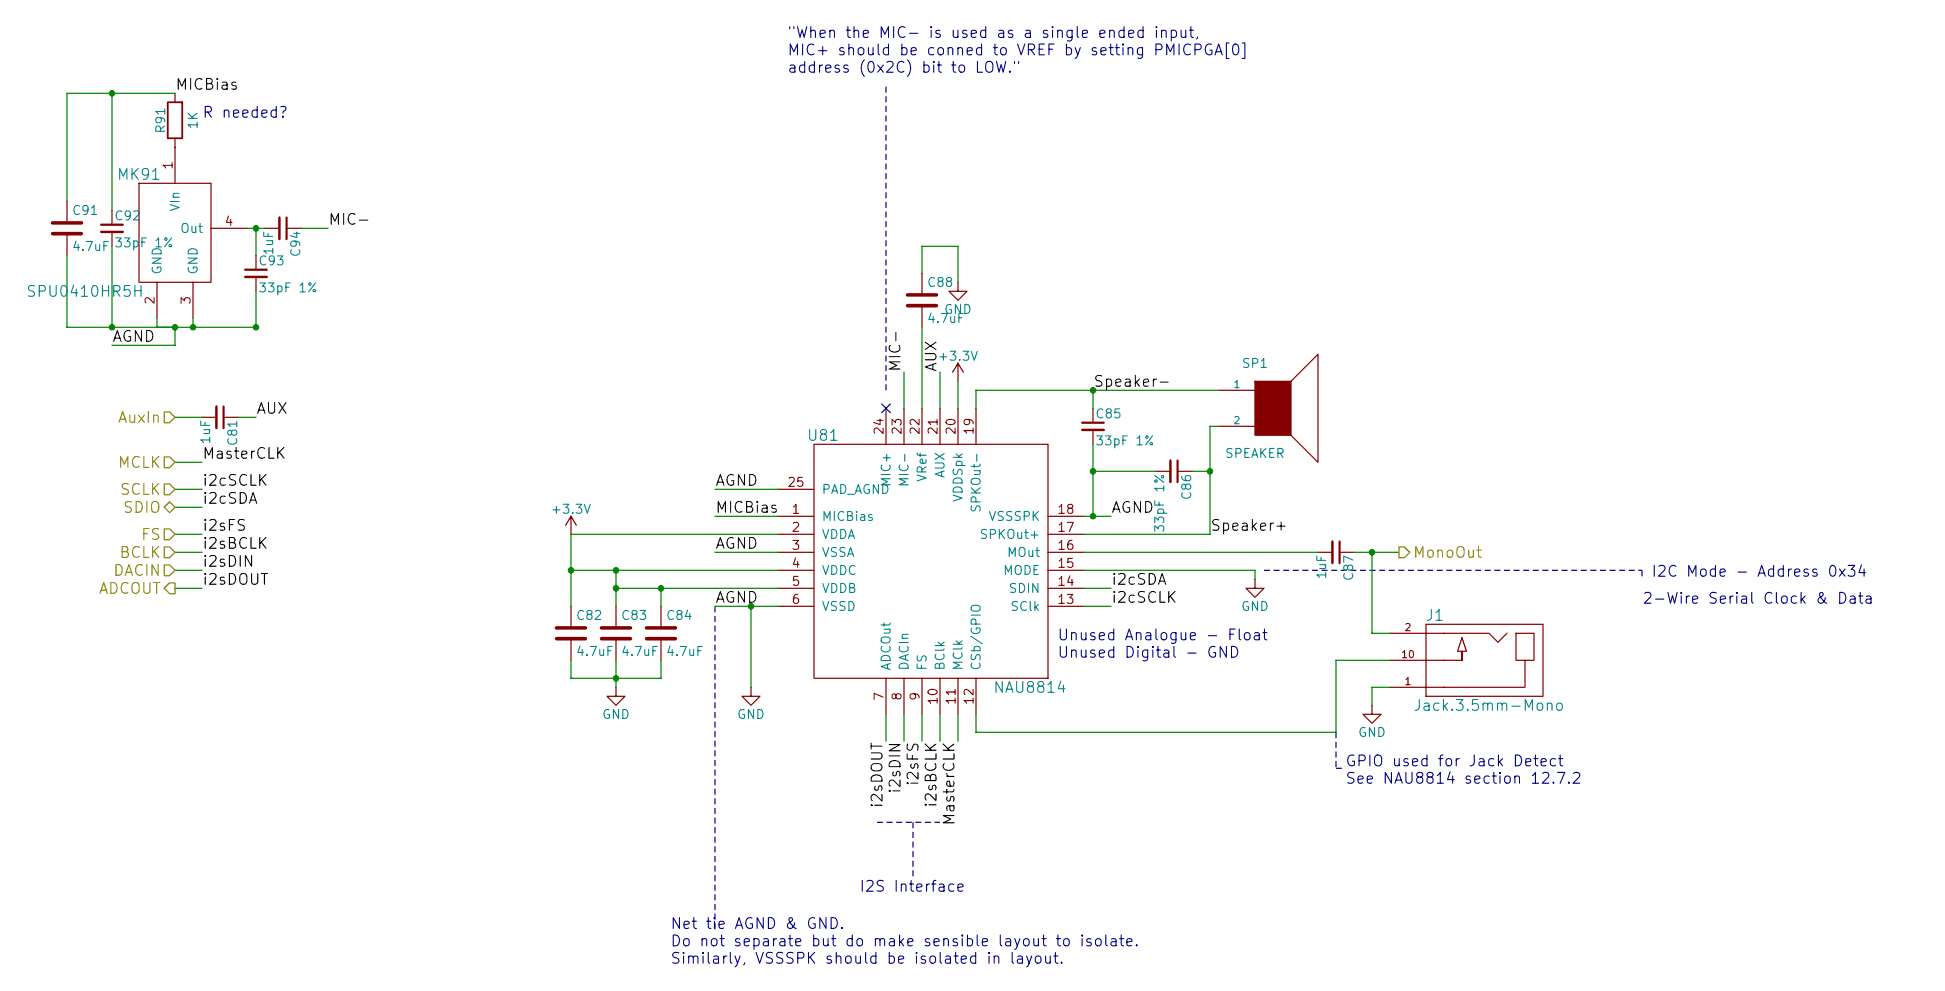
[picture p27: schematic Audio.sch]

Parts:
C81, C87, C94: 1uF; C_0603_HandSoldering; Manufacturer PN GRM188R61C105KA93D; Digikey PN 490-1536-1-ND
C82, C83, C84, C88, C91: 4.7uF; C_0603_HandSoldering; Manufacturer PN CL10B475KQ8NQNC; Digikey PN 1276-2087-1-ND
C85, C86, C92, C93: 33pF 1%; C_0603_HandSoldering; Manufacturer PN CL10C330FB8NNNC; Digikey PN 1276-2262-1-ND
J1: Jack.3.5mm-Mono; 3.5mmMonoTSJack.MJ-3523-SMT.Switch; Manufacturer PN MJ-3523-SMT-TR; Digikey PN CP-3523MJCT-ND
MK91: SPU0410HR5H; MEMSMicrophone-SMT-SPU0410HR5H‐PB; Manufacturer PN SPU0410HR5H-PB; Digikey PN 423-1138-1-ND
R91: 1K; R_0603_HandSoldering; Manufacturer PN RC0603JR-071KL; Digikey PN 311-1.0KGRCT-ND
SP1: SPEAKER; CVS-1508.Speaker.PCPins; Manufacturer PN CVS-1508; Digikey PN 102-2498-ND
U81: NAU8814; NAU8814_QFN-24_4x4mm_Pitch0.5mm_EPAD; Manufacturer PN NAU8814YG; Digikey PN NAU8814YG-ND

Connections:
+3V3: C82.1, C83.1, C84.1, U81.2 (VDDA), U81.4 (VDDC), U81.5 (VDDB), U81.20 (VDDSpk); also elsewhere on the board
/Audio/AUX: C81.1, U81.21 (AUX)
/Audio/MIC-: C94.1, U81.23 (MIC-)
/Audio/MICBias: C91.1, C92.1, R91.2, U81.1 (MICBias)
/Audio/Speaker+: C86.1, SP1.2, U81.17 (SPKOut+)
/Audio/Speaker-: C85.1, SP1.1, U81.19 (SPKOut-)
/AuxAudioIn: C81.2; also elsewhere on the board
/I2C_SCL: U81.13 (SClk); also elsewhere on the board
/I2C_SDA: U81.14 (SDIN); also elsewhere on the board
/IO5: U81.10 (BClk); also elsewhere on the board
/IO16: U81.11 (MClk); also elsewhere on the board
/IO17: U81.8 (DACIn); also elsewhere on the board
/IO18: U81.9 (FS); also elsewhere on the board
/IO27: U81.7 (ADCOut); also elsewhere on the board
/MonoAudioOut: C87.1, J1.2; also elsewhere on the board
unnamed: C87.2, U81.16 (MOut)
unnamed: C88.2, U81.22 (VRef)
unnamed: C93.1, C94.2, MK91.4 (Out)
unnamed: J1.10, U81.12 (CSb/GPIO)
unnamed: MK91.1 (VIn), R91.1

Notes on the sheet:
Unused Analogue - Float Unused Digital - GND
"When the MIC- is used as a single ended input, MIC+ should be conned to VREF by setting PMICPGA[0] address (0x2C) bit to LOW."
I2C Mode - Address 0x34
Net tie AGND & GND. Do not separate but do make sensible layout to isolate. Similarly, VSSSPK should be isolated in layout.
2-Wire Serial Clock & Data
I2S Interface
GPIO used for Jack Detect See NAU8814 section 12.7.2
R needed?

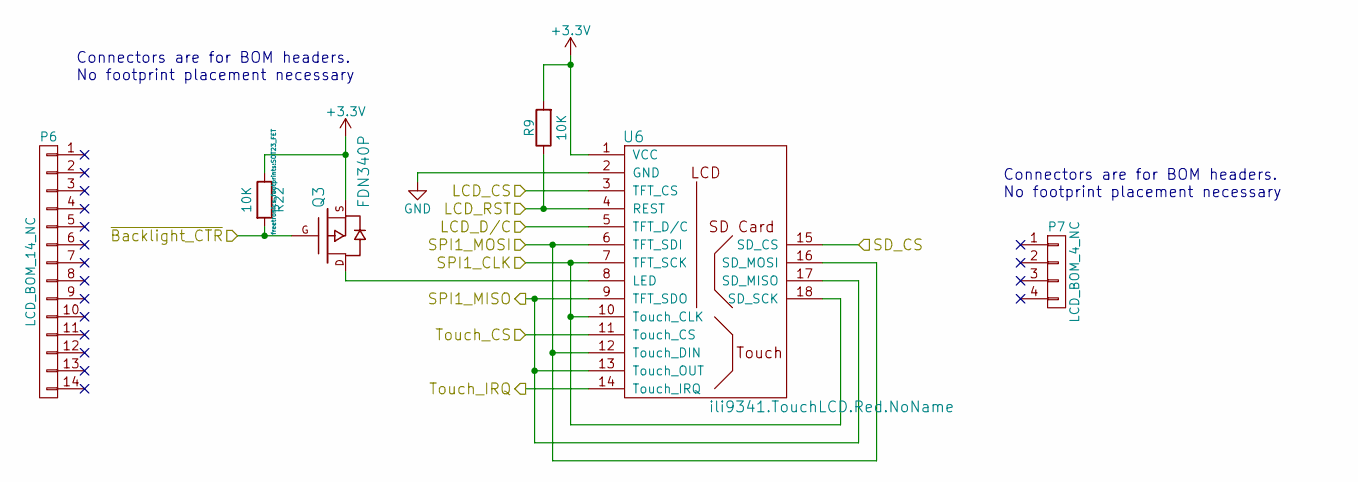
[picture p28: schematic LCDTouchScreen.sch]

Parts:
P6: LCD_BOM_14_NC; Manufacturer PN 929974-01-14-RK; Digikey PN 929974E-01-14-ND
P7: LCD_BOM_4_NC; Manufacturer PN 960104-6202-AR; Digikey PN 3M9515-ND
Q3: FDN340P; SOT23_FET; Manufacturer PN FDN340P; Digikey PN FDN340PCT-ND
R9, R22: 10K; R_0603_HandSoldering; Manufacturer PN RC0603JR-0710KL; Digikey PN 311-10KGRCT-ND
U6: ili9341.TouchLCD.Red.NoName; lcdtouchscreen.2.8inch-red.no-name.ili9341-xpt2046

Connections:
+3V3: Q3.S, R9.2, R22.1, U6.1 (VCC); also elsewhere on the board
/BL_Control: Q3.G, R22.2; also elsewhere on the board
/IO4: U6.5 (TFT_D/C); also elsewhere on the board
/IO12: U6.9 (TFT_SDO), U6.13 (Touch_OUT), U6.17 (SD_MISO); also elsewhere on the board
/IO13: U6.6 (TFT_SDI), U6.12 (Touch_DIN), U6.16 (SD_MOSI); also elsewhere on the board
/IO14: U6.7 (TFT_SCK), U6.10 (Touch_CLK), U6.18 (SD_SCK); also elsewhere on the board
/IO19: U6.3 (TFT_CS); also elsewhere on the board
/IO32: R9.1, U6.4 (REST); also elsewhere on the board
/SD_Sel: U6.15 (SD_CS); also elsewhere on the board
/Touch_INT: U6.14 (Touch_IRQ); also elsewhere on the board
/Touch_Sel: U6.11 (Touch_CS); also elsewhere on the board
unnamed: Q3.D, U6.8 (LED)

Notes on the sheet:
Connectors are for BOM headers. No footprint placement necessary

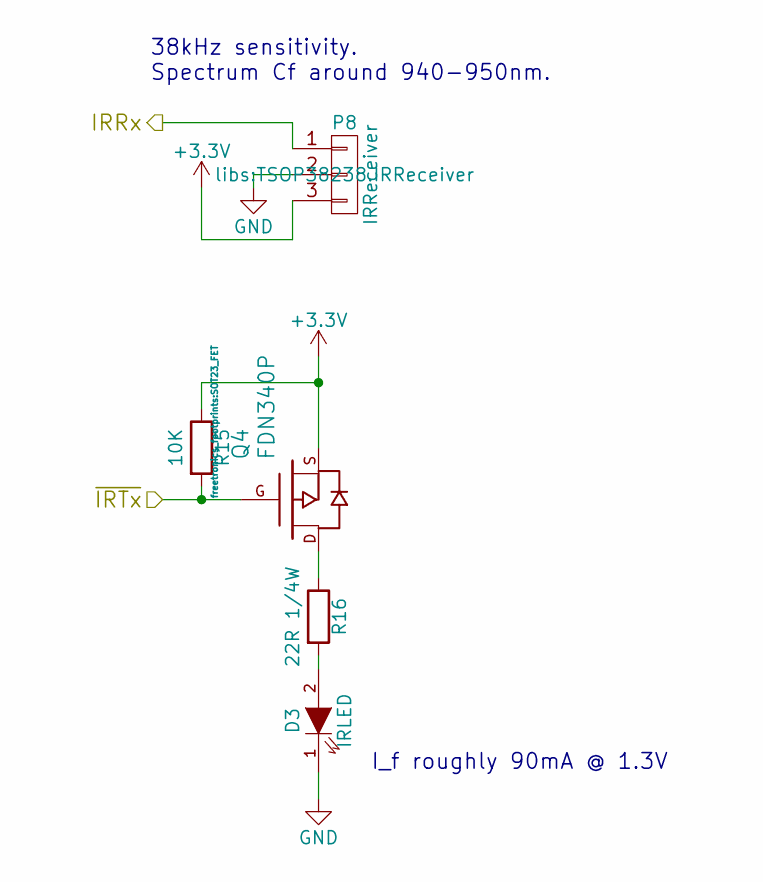
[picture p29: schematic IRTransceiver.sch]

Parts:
D3: IRLED; LED-5MM; Manufacturer PN TSAL6200; Digikey PN 751-1204-ND
P8: IRReceiver; TSOP38238.IRReceiver; Manufacturer PN TSOP38238; Digikey PN 751-1227-ND
Q4: FDN340P; SOT23_FET; Manufacturer PN FDN340P; Digikey PN FDN340PCT-ND
R15: 10K; R_0603_HandSoldering; Manufacturer PN RC0603JR-0710KL; Digikey PN 311-10KGRCT-ND
R16: 22R 1/4W; R_0603_HandSoldering; Manufacturer PN ERJ-PA3J220V; Digikey PN P22.00BZCT-ND

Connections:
+3V3: P8.3, Q4.S, R15.1; also elsewhere on the board
/IO26: Q4.G, R15.2; also elsewhere on the board
/IO35: P8.1; also elsewhere on the board
unnamed: D3.2 (A), R16.2
unnamed: Q4.D, R16.1

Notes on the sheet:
38kHz sensitivity. Spectrum Cf around 940-950nm.
I_f roughly 90mA @ 1.3V

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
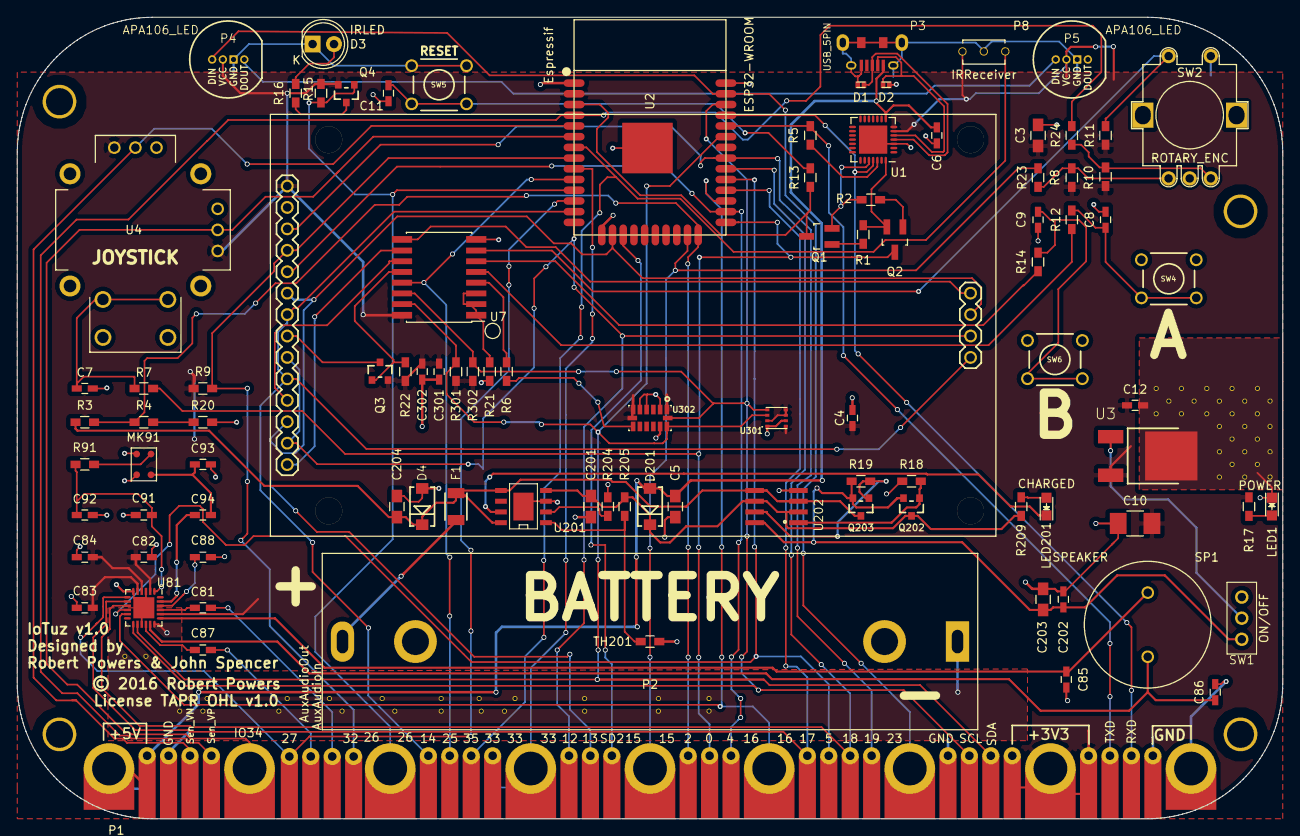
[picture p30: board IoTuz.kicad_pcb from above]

Board: 2 copper layers, 150.0 x 95.0 mm, 101 parts (0 on the bottom side), 82 nets.

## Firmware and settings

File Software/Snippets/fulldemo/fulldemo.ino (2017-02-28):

/***************************************************
  This is our GFX example for the Adafruit ILI9341 Breakout and Shield
  ----> http://www.adafruit.com/products/1651

  Check out the links above for our tutorials and wiring diagrams
  These displays use SPI to communicate, 4 or 5 pins are required to
  interface (RST is optional)
  Adafruit invests time and resources providing this open source code,
  please support Adafruit and open-source hardware by purchasing
  products from Adafruit!

  Written by Limor Fried/Ladyada for Adafruit Industries.
  MIT license, all text above must be included in any redistribution
 ****************************************************/

/*
I2C addresses:
Audio:  0x1A
IO_EXP: 0x20 => Spec sheet says 
"To enter the Read mode the master (microcontroller) addresses the slave
device and sets the last bit of the address byte to logic 1 (address byte read)"
The Wire lib automatically uses the right I/O port for read and write.
ADXL:   0x53
BME230: 0x77 (Temp/Humidity/Pressure)
*/


// https://github.com/CCHS-Melbourne/iotuz-esp32-hardware/wiki has hardware mapping details
#include "iotuz.h"

bool butA   = false;
bool butB   = false;
bool butEnc = false;
// Are we drawing on the screen with joystick, accelerator, or finger?
uint16_t joyValueX;
uint16_t joyValueY;
bool joyBtnValue;

#include "SPI.h"
#include "Adafruit_GFX.h"
// Support for LCD screen
// The latest version of that library may not be up to date and miss a patch for ESP32
// which will cause a compilation error:
// Adafruit_ILI9341.cpp:113:3: error: 'mosiport' was not declared in this scope
// If so, get the latest version from github, or just patch this single line
// https://github.com/adafruit/Adafruit_ILI9341/blob/master/Adafruit_ILI9341.cpp#L98
#include "Adafruit_ILI9341.h"
//#include "ILI9341_t3.h"
// tft adafruit library (games use tft2 a separate library, for which we skip the init
// since the adafruit init works fine for both)
Adafruit_ILI9341 tft = Adafruit_ILI9341(TFT_CS, TFT_DC, TFT_RST);
//ILI9341_t3 tft = ILI9341_t3(TFT_CS, TFT_DC, TFT_RST);


// https://learn.adafruit.com/adafruit-neopixel-uberguide/
// Support for APA106 RGB LEDs
#include "Adafruit_NeoPixel.h"
// APA106 is somewhat compatible with WS2811 or WS2812 (well, maybe not 100%, but close enough to work)
// I have patched the Adafruit library to support ESP32. If that hasn't been merged yet, see this patch
// https://github.com/adafruit/Adafruit_NeoPixel/pull/125
#define RGB_LED_PIN 23
#define NUMPIXELS 2
Adafruit_NeoPixel pixels = Adafruit_NeoPixel(NUMPIXELS, RGB_LED_PIN, NEO_GRB + NEO_KHZ800);
// If you are lacking the ESP32 patch, you will get no error, but the LEDs will not work

// Accelerometer
#include <Adafruit_Sensor.h>
#include <Adafruit_ADXL345_U.h>
Adafruit_ADXL345_Unified accel = Adafruit_ADXL345_Unified(12345);

// Buffer to store strings going to be printed on tft
char tft_str[41];
// TFT Setup End

// Touch screen
#include "XPT2046_Touchscreen.h"
// Touch screen select is on port expander line 6, not directly connected, so the library
// cannot toggle it directly. It however requires a CS pin, so I'm giving it 33, a spare IO
// pin so that it doesn't break anything else.
#define TS_CS_PIN  33
// similarly, the interrupt pin is connected to the port expander, so the library can't use it
// I'm told it is possible to pass an interrupt through the IO expander, but I'm not doing this yet.
//#define TS_IRQ_PIN  0

XPT2046_Touchscreen ts(TS_CS_PIN);  // Param 2 - NULL - No interrupts
//XPT2046_Touchscreen ts(TS_CS_PIN, TS_IRQ_PIN);  // Param 2 - Touch IRQ Pin - interrupt enabled polling

// Joystick Setup
#define JOYSTICK_X_PIN 39
#define JOYSTICK_Y_PIN 34
#define JOYSTICK_BUT_PIN 0

// How many options to display in the rectangle screen
#define NHORIZ 5
#define NVERT 5
// Option names to display on screen
// 40 chars wide, 5 boxes, 8 char per box
// 30 chars high, 5 boxes, 6 lines per box
char* opt_name[NVERT][NHORIZ][3] = {
    { { "", "Finger", "Paint"},  { "Adafruit", "Touch", "Paint"}, { "Joystick", "Absolute", "Paint"}, { "Joystick", "Relative", "Paint"}, { "", "Accel", "Paint"}, },
    { { "Select", "LEDs", "Color"}, { "", "LEDs", "Off"}, { "", "Rotary", "Encoder"}, { "", "Round", "Rects"}, { "Round", "Fill", "Rects"}, },
    { { "", "Text", ""}, { "", "Fill", ""}, { "", "Diagonal", "Lines"}, { "Horizon", "Vert", "Lines"}, { "", "Rectangle", ""}, },
    { { "", "Fill", "Rectangle"}, { "", "Circles", ""}, { "", "Fill", "Circles"}, { "", "Triangles", ""}, { "", "Fill", "Triangles"}, },
    { { "", "Tetris", ""}, { "", "Breakout", ""}, { "", "", ""}, { "", "", ""}, { "", "", ""}, },
};
// tft_width, tft_height, calculated in setup after tft init
uint16_t tftw, tfth;
// number of pixels of each selection box (height and width)
uint16_t boxw, boxh;

typedef enum {
    FINGERPAINT = 0,
    TOUCHPAINT = 1,
    JOYABS = 2,
    JOYREL = 3,
    ACCELPAINT = 4,
    COLORLED = 5,
    LEDOFF = 6,
    ROTARTYENC = 7,
    ROUNDREC = 8,
    ROUNDRECFILL = 9,
    TEXT = 10,
    FILL = 11,
    LINES = 12,
    HORIZVERT = 13,
    RECT = 14,
    RECTFILL = 15,
    CIRCLE = 16,
    CIRCFILL = 17,
    TRIANGLE = 18,
    TRIFILL = 19,
    TETRIS = 20,
    BREAKOUT = 21,
} LCDtest;


void lcd_test(LCDtest choice) {
    switch (choice) {

    case TEXT:
	Serial.print(F("Text                     "));
	Serial.println(testText());
        break;
	 
    case FILL:
	Serial.print(F("Screen fill              "));
	Serial.println(testFillScreen());
        break;

    case LINES:
	Serial.print(F("Lines                    "));
	Serial.println(testLines(ILI9341_CYAN));
	break;

    case HORIZVERT:
	Serial.print(F("Horiz/Vert Lines         "));
	Serial.println(testFastLines(ILI9341_RED, ILI9341_BLUE));
        break;

    case RECT:
	Serial.print(F("Rectangles (outline)     "));
	Serial.println(testRects(ILI9341_GREEN));
	break;

    case RECTFILL:
	Serial.print(F("Rectangles (filled)      "));
	Serial.println(testFilledRects(ILI9341_YELLOW, ILI9341_MAGENTA));
	break;

    case CIRCLE:
	Serial.print(F("Circles (outline)        "));
	Serial.println(testCircles(10, ILI9341_WHITE));
	break;

    case CIRCFILL:
	Serial.print(F("Circles (filled)         "));
	Serial.println(testFilledCircles(10, ILI9341_MAGENTA));
	break;

    case TRIANGLE:
	Serial.print(F("Triangles (outline)      "));
	Serial.println(testTriangles());
	break;

    case TRIFILL:
	Serial.print(F("Triangles (filled)       "));
	Serial.println(testFilledTriangles());
	break;

    case ROUNDREC:
	Serial.print(F("Rounded rects (outline)  "));
	Serial.println(testRoundRects());
	break;

    case ROUNDRECFILL:
	Serial.print(F("Rounded rects (filled)   "));
	Serial.println(testFilledRoundRects());
	break;
    }
}

// maxlength is the maximum number of characters that need to be deleted before writing on top
void tftprint(uint16_t x, uint16_t y, uint8_t maxlength, char *text) {
    if (maxlength > 0) tft.fillRect(x*6, y*8, maxlength*6, 8, ILI9341_BLACK);
    tft.setCursor(x*6, y*8);
    tft.println(text);
}

TS_Point get_touch() {
    // Clear (i.e. set) CS for TS before talking to it
    i2cexp_clear_bits(I2CEXP_TOUCH_CS);
    // Calling getpoint calls SPI.beginTransaction with a speed of only 2MHz, so we need to
    // reset the speed to something faster before talking to the screen again.
    TS_Point p = ts.getPoint();
    // Then disable it again so that talking SPI to LCD doesn't reach TS
    i2cexp_set_bits(I2CEXP_TOUCH_CS);

    return p;
}

void touchcoord2pixelcoord(uint16_t *pixel_x, uint16_t *pixel_y) {
    // Pressure goes from 1000 to 2200 with a stylus but is unreliable,
    // 3000 if you mash a finger in, let's say 2048 range
    // Colors are 16 bits, so multiply pressure by 32 to get a color range from pressure
    // X goes from 320 to 3900 (let's say 3600), Y goes from 200 to 3800 (let's say 3600 too)
    // each X pixel is 11.25 dots of resolution on digitizer, and 15 dots for Y.
    Serial.print("Converted touch coordinates ");
    Serial.print(*pixel_x);
    Serial.print("x");
    Serial.print(*pixel_y);
    //*pixel_x = constrain((*pixel_x-320)/11.25, 0, 319);
    //*pixel_y = constrain((*pixel_y-200)/15, 0, 239);
    *pixel_x = map(*pixel_x, TS_MINX, TS_MAXX, 0, tftw);
    *pixel_y = map(*pixel_y, TS_MINY, TS_MAXY, 0, tfth);
    Serial.print(" to pixel coordinates ");
    Serial.print(*pixel_x);
    Serial.print("x");
    Serial.println(*pixel_y);
}

void finger_draw() {
    uint16_t color_pressure, color;
    static uint8_t update_coordinates = 0;
    TS_Point p = get_touch();

    uint16_t pixel_x = p.x, pixel_y = p.y;
    touchcoord2pixelcoord(&pixel_x, &pixel_y);

    // Writing coordinates every time is too slow, write less often
    if (update_coordinates == 32) {
	update_coordinates = 0;
	sprintf(tft_str, "%d", p.x);
	tftprint(2, 0, 4, tft_str);
	sprintf(tft_str, "%d", p.y);
	tftprint(2, 1, 4, tft_str);
    }

    if (p.z < MINPRESSURE || p.z > MAXPRESSURE) {
	// If we were touching the screen, and we release, show coordinates next time around.
	if (update_coordinates > 0) update_coordinates = 32;
	return;
    }
    
    // Colors are 16 bits, 5 bit: red, 6 bits: green, 5 bits: blue
    // to map a pressure number to colors and avoid random black looking colors,
    // let's seed the color with 2 lowest bits per color: 0001100001100011
    // this gives us 10 bits we need to fill in for which color we'll use,
    color_pressure = p.z-1000;
    if (p.z < 1000) color_pressure = 0;
    color_pressure = constrain(color_pressure, 0, 2047)/2;
    color = tenbitstocolor(color_pressure);
    tft.fillCircle(pixel_x, pixel_y, 2, color);
    update_coordinates++;
}

void read_joystick(bool showdebug=true) {
    // read the analog in value:
    joyValueX = 4096-analogRead(JOYSTICK_X_PIN);
    joyValueY = analogRead(JOYSTICK_Y_PIN);
    joyBtnValue = !digitalRead(JOYSTICK_BUT_PIN);

    if (showdebug) {
	// print the results to the serial monitor:
	Serial.print("X Axis = ");
	Serial.print(joyValueX);
	Serial.print("\t Y Axis = ");
	Serial.print(joyValueY);
	Serial.print("\t Joy Button = ");
	Serial.println(joyBtnValue);
    }
}

// Draw the dot directly to where the joystick is pointing.
void joystick_draw() {
    static int8_t update_cnt = 0;
    // 4096 -> 320 (divide by 12.8) and -> 240 (divide by 17)
    // Sadly on my board, the middle is 1785/1850 and not 2048/2048
    read_joystick();
    uint16_t pixel_x = joyValueX/12.8;
    uint16_t pixel_y = joyValueY/17;
    tft.fillCircle(pixel_x, pixel_y, 2, ILI9341_WHITE);

    // Do not write the cursor values too often, it's too slow
    if (!update_cnt++ % 16)
    {
	sprintf(tft_str, "%d > %d", joyValueX, pixel_x);
	tftprint(2, 0, 10, tft_str);
	sprintf(tft_str, "%d > %d", joyValueY, pixel_y);
	tftprint(2, 1, 10, tft_str);
    }
}

void rotary_encoder() {
    static int16_t   encoder = 0;
    static ButtState encoder_button = ENC_UP;

    int16_t   new_encoder = read_encoder();
    ButtState new_encoder_button = read_encoder_button();

    if (new_encoder != encoder || new_encoder_button != encoder_button) {
	// Serial.print(encoder);
	// Serial.print(" > ");
	// Serial.print(new_encoder);
	// Serial.print(" | ");
	// Serial.print(encoder_button);
	// Serial.print(" > ");
	// Serial.println(new_encoder_button);
	encoder = new_encoder;
	encoder_button = new_encoder_button;
	sprintf(tft_str, "%d/%d", encoder_button, encoder);
	tftprint(0, 0, 10, tft_str);
    }
}

// Move the dot relative to the joystick position (like driving a ball).
void joystick_draw_relative() {
    static uint16_t update_cnt = 0;
    static float pixel_x = 160;
    static float pixel_y = 120;
    // Sadly on my board, the middle is 1785/1850 and not 2048/2048
    read_joystick();
    float move_x = (joyValueX-2300.0)/2048;
    float move_y = (joyValueY-1850.0)/2048;
    int8_t intmove_x = map(joyValueX, 0, 1700, -5, 0);
    int8_t intmove_y = map(joyValueY, 0, 1700, -5, 0);
    if (joyValueX > 1700) intmove_x = map(constrain(joyValueX, 2300, 4096), 2300, 4096, 0, 5);
    if (joyValueY > 1700) intmove_y = map(constrain(joyValueY, 2300, 4096), 2300, 4096, 0, 5);

    tft.fillCircle(int(pixel_x), int(pixel_y), 2, tenbitstocolor(update_cnt % 1024));
    pixel_x = constrain(pixel_x + move_x, 0, 319);
    pixel_y = constrain(pixel_y + move_y, 0, 239);

    // Do not write the cursor values too often, it's too slow
    if (!(update_cnt++ % 32)) {
	sprintf(tft_str, "%.1f (%d) > %d", move_x, intmove_x, int(pixel_x));
	tftprint(2, 0, 16, tft_str);                        
	sprintf(tft_str, "%.1f (%d) > %d", move_y, intmove_y, int(pixel_y));
	tftprint(2, 1, 16, tft_str);
    }
}

void accel_draw() {
    static uint16_t update_cnt = 0;
    static float pixel_x = 160;
    static float pixel_y = 120;
    sensors_event_t event; 
    accel.getEvent(&event);
    float accel_x = -event.acceleration.x;
    // My accelerator isn't really level, it shows 2 when my board is flat
    float accel_y = event.acceleration.y - 2;

    tft.fillCircle(int(pixel_x), int(pixel_y), 2, tenbitstocolor(update_cnt % 1024));
    pixel_x = constrain(pixel_x + accel_x, 0, 319);
    pixel_y = constrain(pixel_y + accel_y, 0, 239);

    // Do not write the cursor values too often, it's too slow
    if (!(update_cnt++ % 32)) {
	sprintf(tft_str, "%.1f > %.1f", accel_x, int(pixel_x));
	tftprint(2, 0, 10, tft_str);
	sprintf(tft_str, "%.1f > %.1f", accel_y, int(pixel_y));
	tftprint(2, 1, 10, tft_str);
    }
}

void draw_color_selector() {
    // 240 pixels high: 75/5 (R) + 75/5 (G) + 75/5 (B)
    // 6 bits of colors for G, 64 colors, 320 pixels wide: 5 pixels wide per color tone
    for (uint8_t i=0; i<3; i++) {
	for (uint8_t j=0; j<64; j++) {
	    uint16_t color = j;
	    
	    // R and B are only 32 shades (5 bits) while G is 64 shades/6 bits.
	    if (i != 1) color /= 2;

	    if (i == 0) color = color << 11;
	    if (i == 1) color = color << 5;
	    tft.fillRect(j*5, i*80, 5, 75, color);
	}
    }   
}

void led_color_selector() {
    uint16_t color_pressure;
    uint8_t colnum, color;
    static uint8_t RGB[3] = {255, 255, 255};

    TS_Point p = get_touch();

    if (p.z < MINPRESSURE || p.z > MAXPRESSURE) {
	return;
    }

    // Red and Green seem reversed on APA106
    pixels.setPixelColor(0, RGB[1], RGB[0], RGB[2]);
    pixels.setPixelColor(1, 255-RGB[1], 255-RGB[0], 255-RGB[2]);
    pixels.show();

    uint16_t pixel_x = p.x, pixel_y = p.y;
    touchcoord2pixelcoord(&pixel_x, &pixel_y);

//    sprintf(tft_str, "%d", pixel_x);
//    tftprint(2, 0, 3, tft_str);
//    sprintf(tft_str, "%d", pixel_y);
//    tftprint(2, 1, 3, tft_str);
    sprintf(tft_str, "%.2x/%.2x/%.2x", RGB[0], RGB[1], RGB[2]);
    tftprint(0, 0, 8, tft_str);

    if (pixel_y < 80) colnum = 0;
    else if (pixel_y < 160) colnum = 1;
    else if (pixel_y < 240) colnum = 2;
    
    color = map(pixel_x, 0, 320, 0, 255);
//    sprintf(tft_str, "col %d: %2x", colnum, color);
//    tftprint(0, 3, 9, tft_str);
    tft.fillRect(0, 80*(colnum+1)-5, 320, 4, ILI9341_BLACK);
    tft.fillTriangle(pixel_x, 80*(colnum+1)-5, pixel_x-2, 80*(colnum+1)-2, pixel_x+2, 80*(colnum+1)-2, ILI9341_WHITE);
    
    RGB[colnum] = color;
}

uint16_t tenbitstocolor(uint16_t tenbits) {
    uint16_t color;

    // TFT colors are 5 bit Red, 6 bits Green, 5 bits Blue, we want to avoid
    // black looking colors, so we seed the last 2 bits of each color to 1
    // and then interleave 10 bits ot color spread across the remaining bits
    // that affect the end color more visibly.
    // 3 highest bits (9-7), get shifted 6 times to 15-13
    // 4 middle  bits (6-3), get shifted 4 times to 10-07
    // 3 lowest  bits (2-0), get shifted 2 times to 04-02
    // This means that if the 10 input bits are 0, the output color is
    // 00011000 01100011 = 0x1863
    color = B00011000*256 + B01100011 + ((tenbits & 0x380) << 6) +
					((tenbits & B01111000) << 4) +
					((tenbits & B00000111) << 2);

//    Serial.print("Color: ");
//    Serial.print(tenbits, HEX);
//    Serial.print(" -> ");
//    Serial.println(color, HEX);
    return color;
}
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
void loop(void) {
    static bool need_select = true;
    static uint8_t select;
    
    if (need_select) {
	reset_tft();
	draw_choices();
	select = get_selection();
	Serial.print("Got menu selection #");
	Serial.println(select);
	tft.fillScreen(ILI9341_BLACK);

	// Kind of random LED illumination
	pixels.setPixelColor(0, (select % 5)*50, 0, 255);
	pixels.setPixelColor(1, 0, (select/5)*64, 255);
	pixels.show();
    }


    // The first 4 demos display x/y coordinate text in the upper left corner
    // After the first time around the loop, need_select gets reset to false
    // and the coordinate text is not rewritten (to save screen drawing time)
    if (select <= 3 and need_select) reset_textcoord();
    switch (select) {
    case FINGERPAINT:
	finger_draw();
	break;
    case TOUCHPAINT:
	// First time around the loop, draw a color selection circle
	if (need_select) touchpaint_setup();
	touchpaint_loop();
	break;
    case JOYABS:
	joystick_draw();
	break;
    case JOYREL:
	joystick_draw_relative();
	break;
    case ACCELPAINT:
	accel_draw();
	break;
    case COLORLED:
	// First time around the loop, draw a color selection circle
	if (need_select) draw_color_selector();
	led_color_selector();
	break;
    case LEDOFF:
	pixels.setPixelColor(0, 0, 0, 0);
	pixels.setPixelColor(1, 0, 0, 0);
	pixels.show();
	// shortcut scan buttons below and go back to main menu
	need_select = true;
	return;
	break;
    case ROTARTYENC:
	rotary_encoder();
	break;
    case TETRIS:
	// First time around the loop, draw a color selection circle
	if (need_select) tetris_setup();
	tetris_loop();
	break;
    case BREAKOUT:
	// First time around the loop, draw a color selection circle
	if (need_select) breakout_setup();
	breakout_loop();
	break;
    default:
	if (select >= 8) {
	    Serial.print("Running LCD Demo #");
	    Serial.println(select);
	    lcd_test((LCDtest) select);
	    delay(500);
	    // shortcut scan buttons below and go back to main menu
	    need_select = true;
	    return;
	}
    }
    // resets need_select to false unless 'B' is pushed.
    scan_buttons(&need_select);
    delay(1);
}


void setup() {
    Serial.begin(115200);
    Serial.println("Serial Begin"); 

    // Basic init and pin mapping that should be common to anything using IoTuz
    iotuz_setup();

    // Hardware SPI on ESP32 is actually slower than software SPI. Giving 80Mhz
    // here does not make things any faster. There seems to be a fair amount of
    // overhead in the fancier hw SPI on ESP32 which is designed to send more than
    // one byte at the time, and only ends up sending one byte when called from an
    // arduino library.
    // Sadly, using software SPI in the adafruit library would prevent SPI from working
    // in the touch screen code which only supports hardware SPI
    // The TFT code runs at 24Mhz as per below, but testing shows that any speed over 2Mhz
    // seems ignored and taken down to 2Mhz
    //SPI.beginTransaction(SPISettings(24000000, MSBFIRST, SPI_MODE0));

    // Talking to the touch screen can only work at 2Mhz, and both drivers change the SPI
    // speed before sending data, so this works transparently.

    // ESP32 requires an extended begin with pin mappings (which is not supported by the
    // adafruit library), so we do an explicit begin here and then the other SPI libraries work
    // with hardware SPI as setup here (they will do a second begin without pin mappings and
    // that will be ignored).
    SPI.begin(SPI_CLK, SPI_MISO, SPI_MOSI);

    // Until further notice, there is a hack to get HW SPI be as fast as SW SPI:
    // in espressif/esp32/cores/esp32/esp32-hal.h after the first define, add
    // #define CONFIG_DISABLE_HAL_LOCKS 1
    // Use with caution, this may cause unknown issues

    // LCD backlight is inverted logic,
    // This turns the backlight off
    // i2cexp_set_bits(I2CEXP_LCD_BL_CTR);
    // And this turns it on
    i2cexp_clear_bits(I2CEXP_LCD_BL_CTR);
    // Note this also initializes the read bits on PCF8574 by setting them to 1 as per I2CEXP_IMASK
    // but iotuz_setup now does this for us earlier up.

    Serial.println("ILI9341 Test!"); 

    tft.begin();
    // read diagnostics (optional but can help debug problems)
    uint8_t x = tft.readcommand8(ILI9341_RDMODE);
    Serial.print("Display Power Mode: 0x"); Serial.println(x, HEX);
    x = tft.readcommand8(ILI9341_RDMADCTL);
    Serial.print("MADCTL Mode: 0x"); Serial.println(x, HEX);
    x = tft.readcommand8(ILI9341_RDPIXFMT);
    Serial.print("Pixel Format: 0x"); Serial.println(x, HEX);
    x = tft.readcommand8(ILI9341_RDIMGFMT);
    Serial.print("Image Format: 0x"); Serial.println(x, HEX);
    x = tft.readcommand8(ILI9341_RDSELFDIAG);
    Serial.print("Self Diagnostic: 0x"); Serial.println(x, HEX); 
    tft.setRotation(3);
    tftw = tft.width(), tfth = tft.height();
    boxw = tftw/NHORIZ, boxh = tfth/NVERT;
    Serial.print("Resolution: "); Serial.print(tftw); 
    Serial.print(" x "); Serial.println(tfth);
    Serial.print("Selection Box Size: "); Serial.print(boxw); 
    Serial.print(" x "); Serial.println(boxh);
    Serial.println(F("Done!"));


    // Tri-color APA106 LEDs Setup
    // Mapping is actually Green, Red, Blue (not RGB)
    pixels.begin();
    pixels.setPixelColor(0, 255, 0, 0);
    pixels.setPixelColor(1, 0, 0, 255);
    pixels.show();

    // ADXL345
    if(!accel.begin()) {
	/* There was a problem detecting the ADXL345 ... check your connections */
	Serial.println("Ooops, no ADXL345 detected ... Check your wiring!");
	while(1);
    }
    accel.setRange(ADXL345_RANGE_16_G);
    displaySensorDetails();

}

// vim:sts=4:sw=4

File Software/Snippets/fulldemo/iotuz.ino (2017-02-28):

#include <Wire.h>
#include "iotuz.h"

// Dealing with the I/O expander is a bit counter intuitive. There is no difference between a
// write meant to toggle an output port, and a write designed to turn off pull down resistors and trigger
// a read request.
// The write just before the read should have bits high on the bits you'd like to read back, but you
// may get high bits back on other bits you didn't turn off the pull down resistor on. This is normal.
// Just filter out the bits you're trying to get from the value read back and keep in mind that when
// you write, you should still send the right bit values for the output pins.
// This is all stored in i2cexp which we initialize to the bits used as input:
#define I2CEXP_IMASK ( I2CEXP_ACCEL_INT + I2CEXP_A_BUT + I2CEXP_B_BUT + I2CEXP_ENC_BUT + I2CEXP_TOUCH_INT )
// Any write to I2CEXP should contain those mask bits so allow reads to work later
uint8_t i2cexp = I2CEXP_IMASK;

// I2C/TWI success (transaction was successful).
#define ku8TWISuccess    0
// I2C/TWI device not present (address sent, NACK received).
#define ku8TWIDeviceNACK 2
// I2C/TWI data not received (data sent, NACK received).
#define ku8TWIDataNACK   3
// I2C/TWI other error.
#define ku8TWIError      4

void pcf8574_write(uint8_t dt)
{
    uint8_t error;

    Wire.beginTransmission(I2C_EXPANDER);
    // Serial.print("Writing to I2CEXP: ");
    // Serial.println(dt);
    Wire.write(dt);
    error = Wire.endTransmission();
    if (error != ku8TWISuccess) {
	    // FIXME: do something here if you like
    }
}

// To clear bit #7, send 128
void i2cexp_clear_bits(uint8_t bitfield)
{
    // set bits to clear to 0, all other to 1, binary and to clear the bits
    i2cexp &= (~bitfield);
    pcf8574_write(i2cexp);
}

// To set bit #7, send 128
void i2cexp_set_bits(uint8_t bitfield)
{
    i2cexp |= bitfield;
    pcf8574_write(i2cexp);
}

uint8_t i2cexp_read()
{
    // For read to work, we must have sent 1 bits on the ports that get used as input
    // This is done by i2cexp_clear_bits called in setup.
    Wire.requestFrom(I2C_EXPANDER, 1);	// FIXME: deal with returned error here?
    while (Wire.available() < 1) ;
    uint8_t read = ~Wire.read();	// Apparently one has to invert the bits read
    // When no buttons are pushed, this returns 0x91, which includes some ports
    // we use as output, so we do need to filter out the ports used as read.
    // Serial.println(read, HEX);
    return read;
}

// grey code
// http://hades.mech.northwestern.edu/index.php/Rotary_Encoder
// also read up on 'Understanding Quadrature Encoded Signals'
// https://www.pjrc.com/teensy/td_libs_Encoder.html
int8_t enc_states[] = {0,-1,1,0,1,0,0,-1,-1,0,0,1,0,1,-1,0};
volatile int16_t encoder0Pos = 0;
int16_t old_encoder0Pos = 0;
uint8_t old_AB = 0;

/* returns change in encoder state (-1,0,1) */
void read_encoder_ISR() 
{
    old_AB <<= 2;
    old_AB |= ((digitalRead(ENCODERB_PIN))?(1<<1):0) | ((digitalRead(ENCODERA_PIN))?(1<<0):0);
    encoder0Pos += ( enc_states[( old_AB & 0x0f )]);
}

int16_t read_encoder() 
{
    return encoder0Pos;
}

bool encoder_changed() {
    if (encoder0Pos != old_encoder0Pos)
    {
	old_encoder0Pos = encoder0Pos;
	return true;
    }
    return false;
}

ButtState read_encoder_button() 
{
    static bool butEnc = false;
    uint8_t butt_state = i2cexp_read() & I2CEXP_ENC_BUT;

    if (butt_state && !butEnc)
    {
	butEnc = true;
	//Serial.println("Encoder Button Pushed");
	return ENC_PUSHED;
    }
    if (!butt_state && butEnc)
    {
	butEnc = false;
	//Serial.println("Encoder Button Released");
	return ENC_RELEASED;
    }
    return (butt_state?ENC_DOWN:ENC_UP);
}

void iotuz_setup()
{
    pinMode (ENCODERA_PIN, INPUT_PULLUP);
    pinMode (ENCODERB_PIN, INPUT_PULLUP);

    pinMode(SPI_MOSI, OUTPUT);
    pinMode(SPI_MISO, INPUT);
    pinMode(SPI_CLK, OUTPUT);

    // Joystick Setup
    pinMode(JOYSTICK_BUT_PIN, INPUT_PULLUP);

    // TFT Setup
    pinMode(TFT_CS, OUTPUT);
    pinMode(TFT_DC, OUTPUT);
    pinMode(TFT_RST, OUTPUT);

    // required for i2exp to work
    Wire.begin();
    // turn off the LCD by default and init other bits (the ones that are read)
    i2cexp_set_bits(I2CEXP_LCD_BL_CTR);

    // Initialize rotary encoder reading and decoding
    attachInterrupt(ENCODERA_PIN, read_encoder_ISR, CHANGE);
    attachInterrupt(ENCODERB_PIN, read_encoder_ISR, CHANGE);
}

// vim:sts=4:sw=4

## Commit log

2016-10-09 Initial Commit
    Dual power supply should be working at this stage.
    [InternetOfTux.kicad_pcb, InternetOfTux.sch, power.sch]
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2016-10-19 Added USB/Serial Bridge, buttons and auto flash.
    [InternetOfTux.sch, power.sch]
2016-10-21 Added Arduino header footprint
    [InternetOfTux.sch]
2016-10-21 Renamed files to the new project name.
    [IoTuz.kicad_pcb, IoTuz.sch]
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2016-10-24 First spin at board design.
    [IoTuz.sch, power.sch]
2016-10-26 Removed 5V components.
    And solar. At this point they aren't needed.
    [IoTuz.sch, power.sch]
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2016-10-26 Updated design
    Added external sheets for sensors and buttons.
    Removed the Arduino header.
    Removed Power elements that aren't needed.
    [IoTuz.kicad_pcb, IoTuz.sch, controller.sch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]
2016-10-26 Updated pcb to start placing components.
    [IoTuz.kicad_pcb, IoTuz.sch, controller.sch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]
2016-10-27 Some notes & adding sheets.
    [Audio.sch, IRTransceiver.sch, IoTuz.sch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]
2016-10-28 Changed 3v3 regulator to higher current buck converter.
    [Audio.sch, IRTransceiver.sch, IoTuz.sch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]
2016-10-28 Output cap on buck.
    [IoTuz.sch, controller.sch, power.sch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]
2016-10-31 Added EC11 Rotary Encoder footprint
    [IoTuz.kicad_pcb, IoTuz.sch, controller.sch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]
2016-10-31 Added footprint for QDTech 3.2in TFT screen
    [IoTuz.kicad_pcb, _saved_IoTuz.sch]
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2016-10-31 Added footprint for LCD.
    [Audio.sch, IRTransceiver.sch, IoTuz.sch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]
2016-11-01 updated: added bme280 3dshape model.
    [IoTuz.kicad_pcb]
2016-11-01 updated: added qdtech-lcd 3dshape model.
    [IoTuz.kicad_pcb]
2016-11-01 Markup IO allocation & add some datasheets.
    [IoTuz.sch]
2016-11-01 updated: added esp-wroom-32 3dshape model.
    [IoTuz.kicad_pcb]
2016-11-02 NAU8814 schematic component. LXDC2XQ footprint update. Kludge for forward/back slash in lib table needs addressing.
    [Audio.sch, IRTransceiver.sch, IoTuz.sch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]
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2016-11-02 Audio choices being narrowed.
    [Audio.sch, IoTuz.sch]
2016-11-02 Added reference manual, updated .gitignore to avoid .bck kicad backup files.
2016-11-02 updated: added adxl345 3dshape model.
    [IoTuz.kicad_pcb]
2016-11-02 updated: assigned default sot23 3dshape models to the freetronics fets.
    [IoTuz.kicad_pcb]
2016-11-02 updated: assigned default soic housings to cn3063 and mcp6002.
    [IoTuz.kicad_pcb]
2016-11-03 updated: assigned model for joystick and added new model for the battery holder.
    [IoTuz.kicad_pcb]
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2016-11-03 Audio work, more to do.
    [Audio.sch, IRTransceiver.sch, IoTuz.sch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]
2016-11-04 Audio updates & markup. Choices to be made, but can be completed just by adding i2s, i2c, & MCLK I/O.
    [Audio.sch]
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2016-11-04 Removed duplicate stabilizing capacitors.
    [IoTuz.sch]
2016-11-04 Added Alligator clip points.
    [Audio.sch, IoTuz.kicad_pcb, IoTuz.sch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]
2016-11-04 Speaker choice changed & footprint creation.
    [Audio.sch]
2016-11-04 Begin adding fields to components.
    [Audio.sch]
2016-11-05 IR receiver schematic & footprint.
    [Audio.sch, IRTransceiver.sch]
2016-11-05 IRTx & forward slashing the fp-lib-table.
    [IRTransceiver.sch, IoTuz.sch]
2016-11-05 Reference documents added & renamed to be more descriptive.
    [IRTransceiver.sch]
2016-11-05 Messing with John's layout. You're welcome.
    [IRTransceiver.sch, IoTuz.kicad_pcb]
2016-11-05 Rotated joystick to fit better. X and Y are swapped.
    [IoTuz.kicad_pcb, controller.sch]
2016-11-05 Removed PRGM button. placed some components.
    PGRM button can be performed by joystick.
    CHRG led removed.
    placed some components.
    [Audio.sch, IRTransceiver.sch, IoTuz.kicad_pcb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]
2016-11-05 Footprint assigned for IR receiver.
    [IRTransceiver.sch]
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2016-11-07 Some small caps on the speaker output to balance and filter.
    [Audio.sch]
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2016-11-07 More component info & rework footprint for the USB connector.
    [IoTuz.sch]
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2016-11-07 Updated Alligator tabs
    Incomplete. Included to provide ideas.
    [Audio.sch, IRTransceiver.sch, IoTuz.kicad_pcb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]
2016-11-08 BOM information to schematic. Power & main sheets mostly.
    [Audio.sch, IRTransceiver.sch, IoTuz.sch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]
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2016-11-08 Mounting points. Need to add for LCD as well.
    [IoTuz.sch]
2016-11-08 Updated alligators to be a 25 pin unit.
    [_saved_IoTuz.sch]
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2016-11-12 Changes to audio. Added 3.5mm TRS jack footprint.
    [Audio.sch, IoTuz.sch]
2016-11-12 Added 3.5mm jack and header pin to audio schematic.
    [Audio.sch, IRTransceiver.sch, IoTuz.sch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]
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2016-11-13 Modify alligator so it doesn't overhang board.
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2016-11-14 F.CU & B.CU fills. Need to modify or remove parts of F.Cu.
    [IoTuz.kicad_pcb]
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2016-11-14 Fixing up pours.
    [IoTuz.kicad_pcb]
2016-11-14 Most routing done, some pours and tracks to clean up.
    [IoTuz.kicad_pcb]
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2016-11-14 Just caught I/O error on controller sch. XY reversed.
    [IoTuz.kicad_pcb, IoTuz.sch, controller.sch]
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2016-11-14 fixed: missing materials on select faces in red lcd model.
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2016-11-14 Change design rules so it passes DRC (totally legit) & modify QFN for clearance on corner pads.
    [IoTuz.kicad_pcb]
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2016-11-14 Mounting points and modify alligator connector to fit.
    [IoTuz.kicad_pcb, IoTuz.sch]
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2016-11-15 Modifications for BOM generation & documentation. LAST COMMIT WAS v0.1 PROTOTYPE.
    [Audio.sch, IRTransceiver.sch, IoTuz.BOM.csv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]
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2016-11-28 Fixed APA106 wiring in Schematic.
    [IoTuz.sch]
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2016-12-05 Fixed mechanical keepouts.
    [IoTuz.kicad_pcb]
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2016-12-06 Changes to v0.1 pinout errors. v0.1->Minimal vNext changes. Most routing reworked. Closes #12, closes #18, closes #19, closes #21.
    [IoTuz.kicad_pcb, IoTuz.sch]
2016-12-06 Added 10k resistors on pins from quadrature out on encoder. Fixes #16.
    [Audio.sch, IRTransceiver.sch, IoTuz.kicad_pcb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]
2016-12-06 BOM changes to fix #15, fix #24.
    [IRTransceiver.sch, IoTuz.kicad_pcb, controller.sch]
2016-12-06 Put via stitching back on LDO to fix #23.
    [IoTuz.kicad_pcb]
2016-12-06 Redesigned Alligator pin assignments
    [IoTuz.kicad_pcb, IoTuz.sch]
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2016-12-07 Changes for BOM generation. Corrections to redundant BOM items.
    [IoTuz.BOM.csv, IoTuz.sch, LCDTouchScreen.sch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]
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2016-12-12 Incremental overlay fixes.
    [IoTuz.kicad_pcb]
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2016-12-12 Fixing up references & back conference logo to text.
    [IoTuz.kicad_pcb]
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2016-12-13 Closes #4 as it was fixed ages ago. More touches to pours, overlays.
    [IoTuz.kicad_pcb]
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2016-12-13 Fixing up copper disconnects.
    [IoTuz.kicad_pcb]
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2016-12-13 Changed all via stitching vias to get rid of ref/val presentation.
    [IoTuz.kicad_pcb]
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2016-12-30 Updated alligator pads
    Now mask both sides.
    PCB text updates.
    [IoTuz.kicad_pcb]
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2017-01-15 Hand-soldering documentation corrections.
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2017-01-15 Hand-soldering documentation first pass minor fixes.
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2017-01-15 Hand-soldering documentation first pass improvements based on feedback. - Mentioned MCP6002 (U202) alteration - Include LiPo battery fail image - Clearer IR transmitter LED orientation description - 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
2017-01-17 Add help for compilation error with old adafruit library
    [graphicstest.ino]
2017-01-19 Fix MISO pinmode, add comments
    Please make sure that these comments are sane, they are based on what I understand from reading stuff :)
    [graphicstest.ino]
2017-01-20 pressure coloring changes.
    Added a fancy pressure to color table, which in the end doesn't provide
    great color output, but at least it guranteed we won't be writing in
    dark colors.
    Added coordinates writing on the screen
    [fulldemo.ino]
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2017-01-29 Samples/fulldemo: Move enum into separate header.
    The arduino environment seems to get easily confused if
    enums and structs are defined in the main sketch and wants
    them to be in headers it can parse. Something about it
    rearranging the sketch to put all includes first. Without
    this change I get compile errors with Arduino 1.6.4 like:
    fulldemo:73: error: variable or field 'lcd_test' declared void
    fulldemo:73: error: 'LCDtest' was not declared in this scope
    fulldemo:75: error: 'TS_Point' does not name a type
    variable or field 'lcd_test' declared void
    [fulldemo.ino]
2017-01-31 Add STLs for v1.0 of a 3D-printable case
    [Bottom_Case.stl, Button Caps_ButtonA-20.5mm_Button Caps.stl, Button Caps_ButtonA-6mm_Button Caps.stl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]
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2017-02-03 Added adafruit touchpaint demo.
    - reverted changes from thaytan to get around a broken arduino IDE.
    Sorry, those errors you got don't make sense and I'm not convinced at
    all that the fixes are necessary, try upgrading your IDE.
    (all symbols used are defined before they are used, and they're defined
    in the same file, so there is no reason for the compiler to complain
    that they are absent, and I prefer to keep all of them in one file for
    now)
    If you can convince me that your arduino IDE is right and that mine is
    wrong for compiling the code as is without errors, let me know and I'll
    revisit my stance
    - split off adafruit demos I didn't write back into their own files to
    separate code I'm re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
    [adafruit_breakouttouchpaint.ino, adafruit_graphicstest.ino, fulldemo.ino]
2017-02-18 3 rotary decoders.
    - one from loop(), prevents other things from being done
    - one from an ESP32 timer (works well)
    - one attempt via pin interrupts (does not work well, but demo to improve)
    [EncoderTest.ino, EncoderTestIntr.ino, EncoderTestPinIntr.ino]
2017-02-18 Replaced interrupt decoder with grey code which works perfectly reliably.
    No more debouncing problems, yeah!
    [EncoderTestPinIntr.ino]
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2017-02-21 Added rotary encoder test and support in breakout.
    - breakout now supports rotary encoder
    - added more center slope for the joystick since mine was still drifting
    in the center.
    - extended iotuz.c|h with more common data/methods
    [EncoderTestPinIntrButt.ino, breakout.cpp, fulldemo.ino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]
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

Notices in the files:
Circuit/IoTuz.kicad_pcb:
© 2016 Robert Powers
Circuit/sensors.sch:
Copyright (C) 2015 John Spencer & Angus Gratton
